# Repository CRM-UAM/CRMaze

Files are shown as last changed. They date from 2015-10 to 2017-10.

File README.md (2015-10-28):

# CRMaze
Open source robot for maze solving + line following

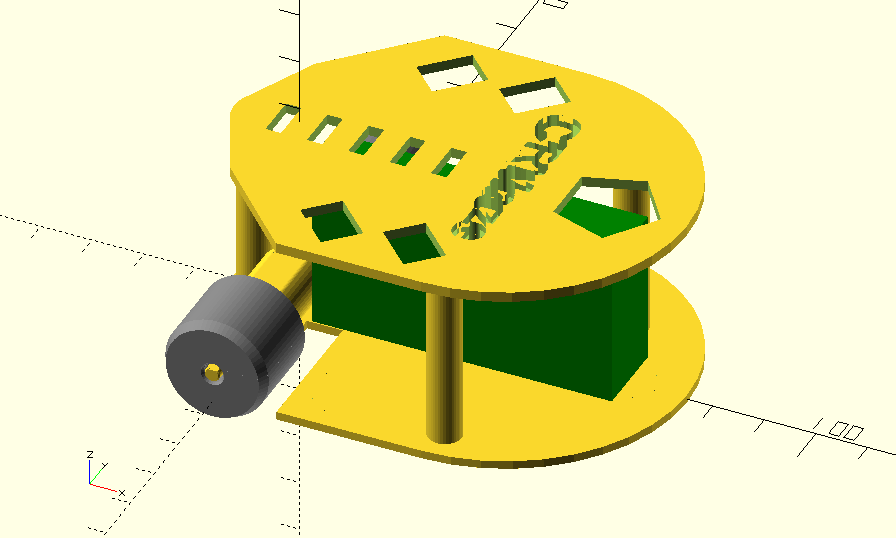
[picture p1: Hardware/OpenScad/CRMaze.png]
  

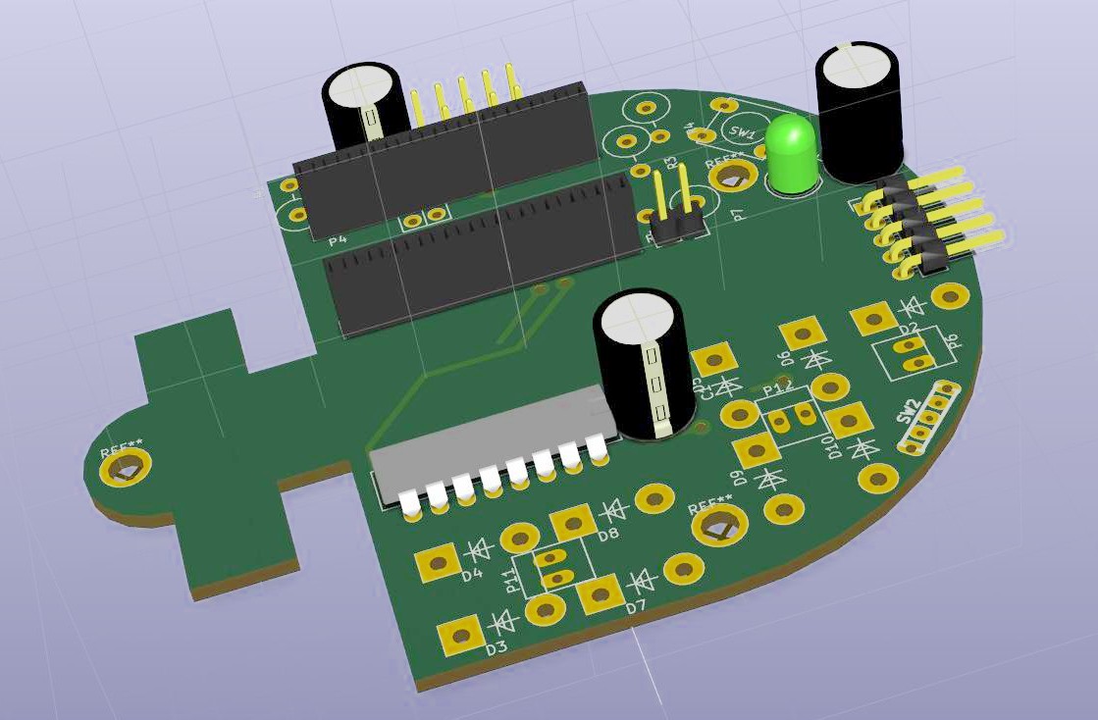
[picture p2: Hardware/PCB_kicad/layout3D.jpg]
  

Authors
--
**Víctor Uceda & Carlos García**  
Club de Robótica-Mecatrónica, Universidad Autónoma de Madrid (CRM-UAM)  
<http://crm-uam.github.io>  

License
--
License: **Attribution - Share Alike - Creative Commons (<http://creativecommons.org/licenses/by-sa/4.0/>)**  

Disclaimer  
--
This hardware/software is provided "as is", and you use the hardware/software at your own risk. Under no circumstances shall any author be liable for direct, indirect, special, incidental, or consequential damages resulting from the use, misuse, or inability to use this hardware/software, even if the authors have been advised of the possibility of such damages.

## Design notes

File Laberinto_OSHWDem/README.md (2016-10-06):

Paredes modulares para probar el laberinto de la OSHWDem
=

Dentro de poco es la OSHWDem Coruña (<http://oshwdem.org/>), el mayor evento que fomenta la tecnología abierta en España.

Una de las competiciones es el laberinto (<http://rules.oshwdem.org/labirinto_es>). Para poder participar, necesitábamos un laberinto en el que probar los robots con cierta antelación.

Para ello hemos diseñado el siguiente sistema paramétrico con las medidas reales que se utilizarán en la competición. Esperemos que os sea de utilidad, y... ¡nos vemos en la OSHWDem! :-)

¡¡¡OJO!!! Las paredes_laberinto.stl son 1cm más largas de la cuenta! Sentimos las molestias que esto haya podido ocasionar... Nos hemos dado cuenta tarde :-S
--

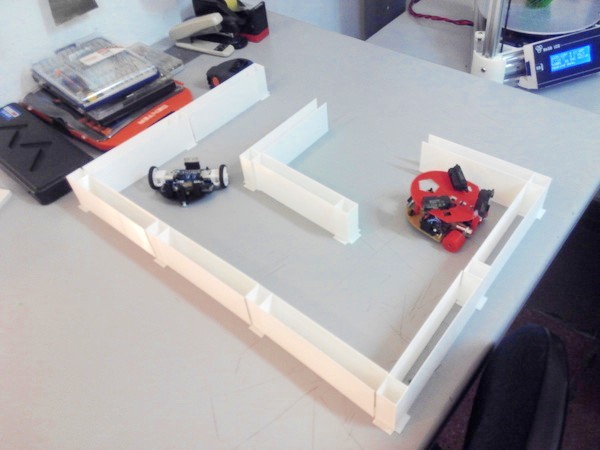
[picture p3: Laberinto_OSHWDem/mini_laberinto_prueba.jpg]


Descarga el diseño
=

- Código fuente OpenSCAD: [paredes_laberinto.scad](paredes_laberinto.scad)
- STL de la pieza suelta: [pieza_suelta.stl](pieza_suelta.stl)
- STL de la base de imprusión: [paredes_laberinto.stl](paredes_laberinto.stl)

Más fotos
=

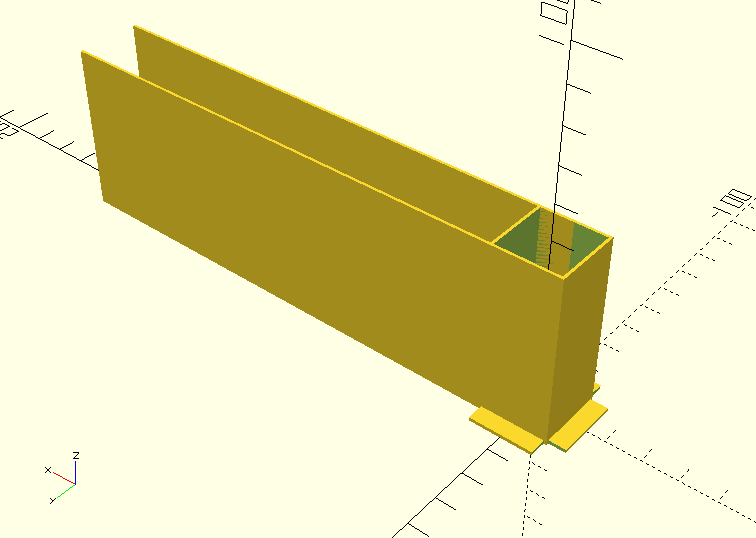
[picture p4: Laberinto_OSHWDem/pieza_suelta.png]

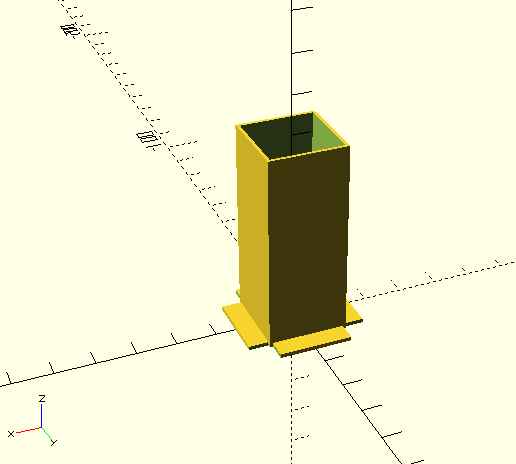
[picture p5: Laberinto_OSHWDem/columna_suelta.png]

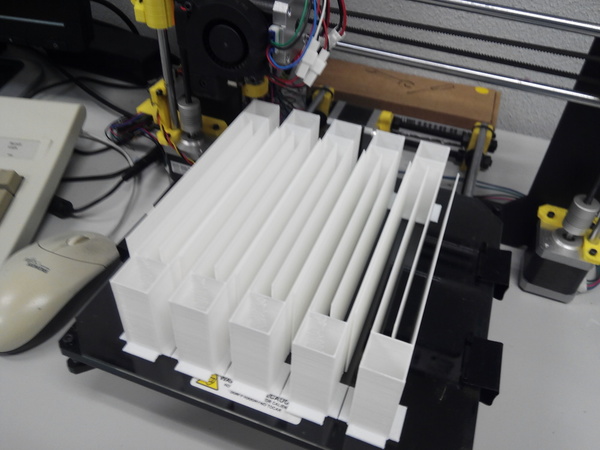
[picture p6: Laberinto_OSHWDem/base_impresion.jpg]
  
*El diseño permite imprimir muchas piezas juntas*  

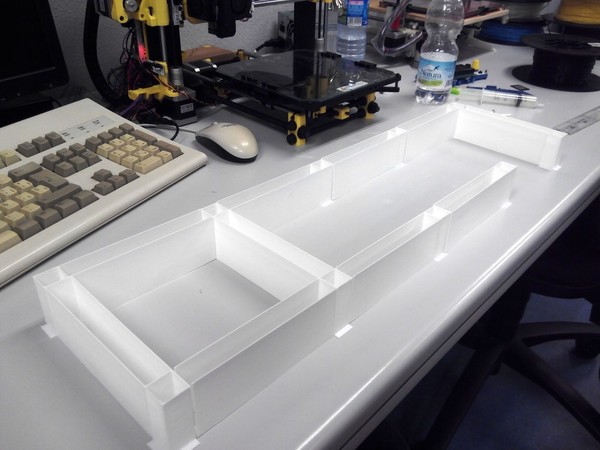
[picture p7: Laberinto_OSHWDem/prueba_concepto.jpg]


Diseñado por Víctor Uceda (@VictorUceda), Eduardo Hilario (@eduhs) y Carlos García (@CarlosGS)

Club de Robótica-Mecatrónica, Universidad Autónoma de Madrid (<http://crm.ii.uam.es>)

Licencia: Public Domain

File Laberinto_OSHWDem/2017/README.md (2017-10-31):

# Pilares para el laberinto de la OSHWDem 2017

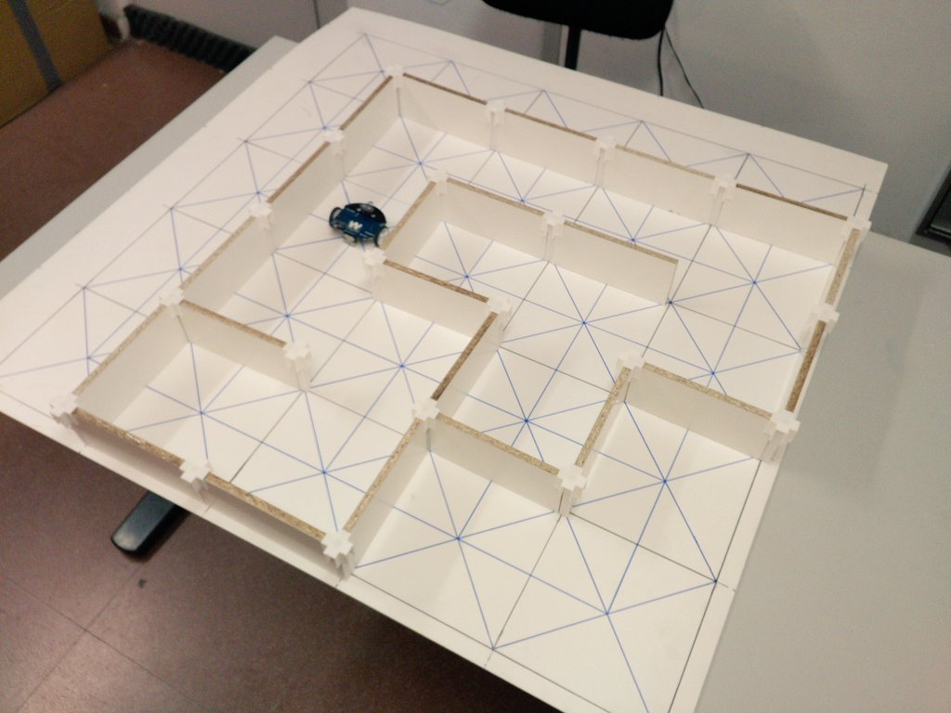
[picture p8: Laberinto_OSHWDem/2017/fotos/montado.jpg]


# Instrucciones

- Cortar tablillas de dimensión 170x80x10mm. Esto lo hacen gratis en la tienda AKI, a partir de tablas de madera conglomerada con laminación blanca.
- Imprimir las columnas de soporte y montarlo como en las fotos.

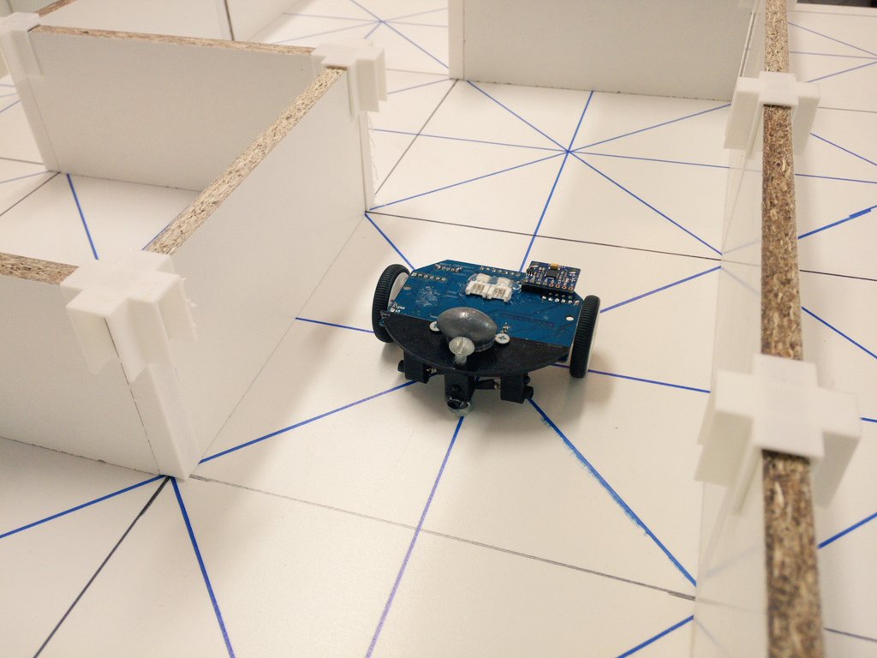
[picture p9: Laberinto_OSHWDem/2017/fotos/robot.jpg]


# Nota: El grosor de las paredes oficiales es 12mm en vez de 10mm. La cuadrícula tiene el mismo tamaño.

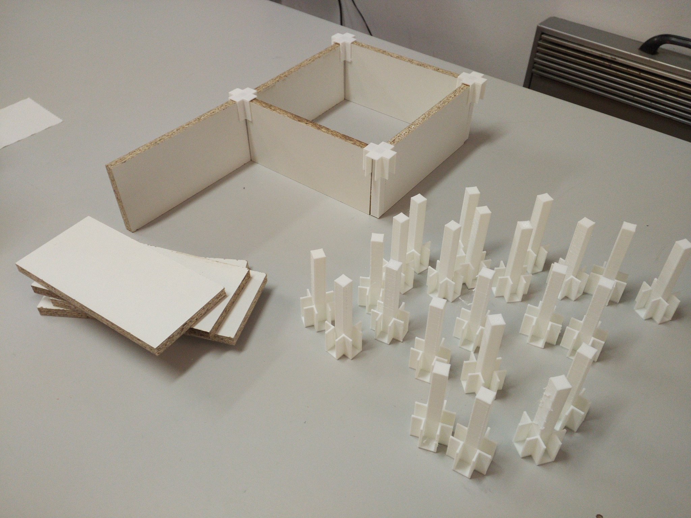
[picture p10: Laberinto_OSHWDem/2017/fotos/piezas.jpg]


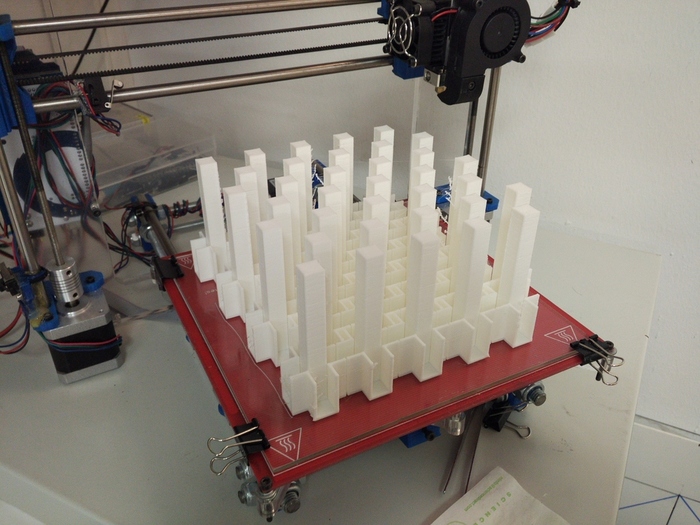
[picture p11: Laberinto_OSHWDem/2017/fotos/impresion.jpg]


# Nota 2: La altura es superior al original para facilitar la fabricación de las tablillas (en el AKI no cortan medidas inferiores).

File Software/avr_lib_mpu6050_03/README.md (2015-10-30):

From <http://davidegironi.blogspot.com.es/2013/02/avr-atmega-mpu6050-gyroscope-and.html>  

==================================================
MPU6050 lib
==================================================
= Copyright (c) Davide Gironi, 2012              =
= http://davidegironi.blogspot.it/               =
==================================================

The MPU-60X0 has an embedded 3-axis MEMS gyroscope, a 3-axis MEMS accelerometer,
and a Digital Motion Processor (DMP) hardware accelerator engine with an
auxiliary I2C port that interfaces to 3rd party digital sensors such
as magnetometers.

Two attitude extimation mode are implemented:
 * internal DMP processor
 * mahony filter

Gyro calibration is suggested to get more accurate parameters. To calibrate the
device read the raw values using the get non calibrated mode then calculate
the offset.

Setup parameters are stored in file mpu6050.h

Devel Notes
-----------
This library was developed on Eclipse, built with avr-gcc on Atmega168 @ 16MHz.
If you include <math.h> add libm library to linker.

License
-------
Please refer to LICENSE file for licensing information.

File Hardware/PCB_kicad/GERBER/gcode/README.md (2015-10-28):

The Gcode files were generated with FlatCAM and post processed:

* all of them were mirrored vertically from bCNC
* the drill file was optimized with bCNC to reduce milling time
* manually removed the "interior" pass of FlatCAM's output, and pocketed the outer edge with bCNC (with the "cut" tool and 0.45mm depth increments)

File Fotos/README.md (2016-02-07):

Participó en la OSHWDem 2015. [Entrada en el blog](http://crm-uam.github.io/blog/2015/11/07/OSHWDem.html)

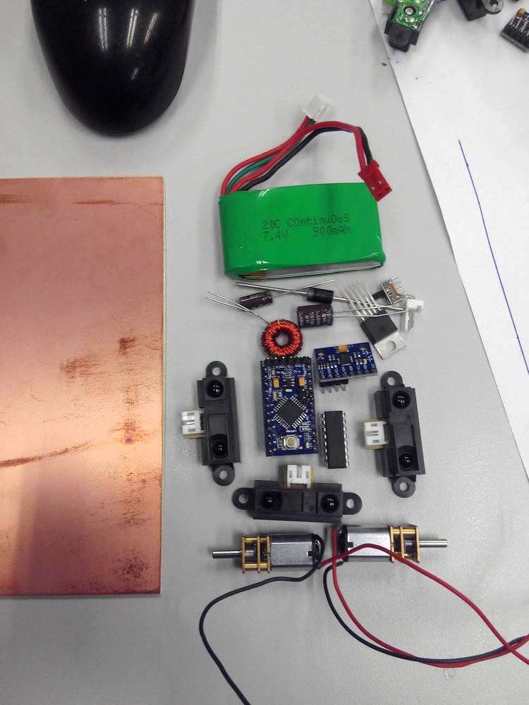
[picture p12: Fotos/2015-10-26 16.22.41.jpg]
foto


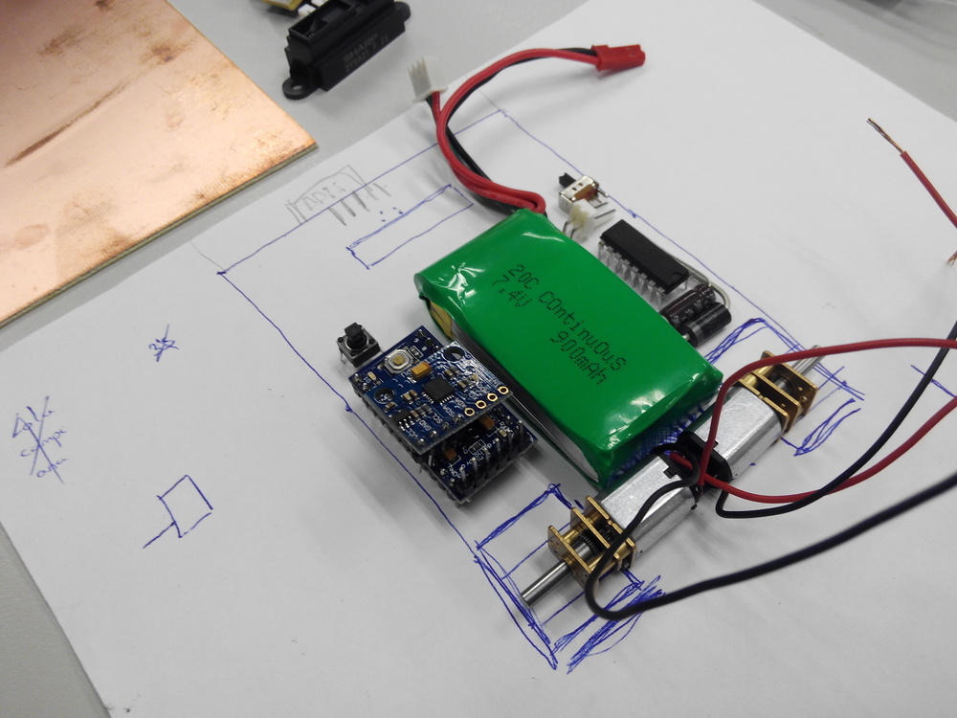
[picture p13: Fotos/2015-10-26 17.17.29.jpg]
foto


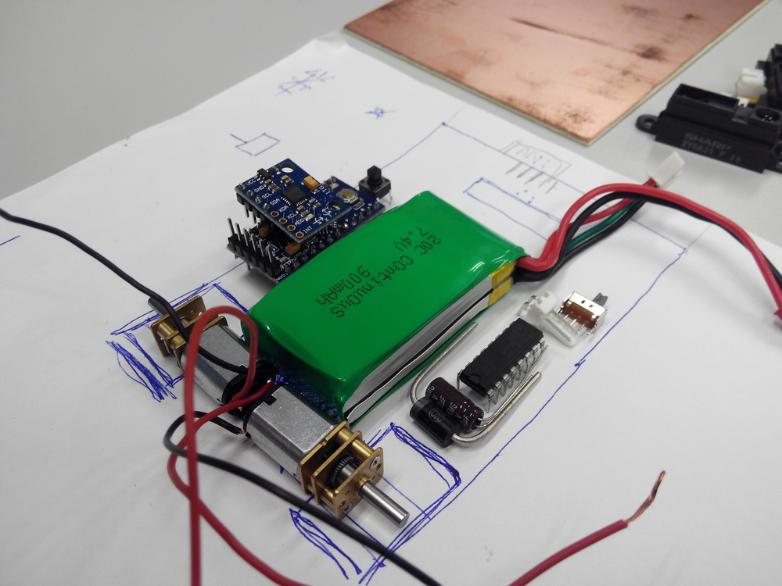
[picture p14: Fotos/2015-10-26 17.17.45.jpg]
foto


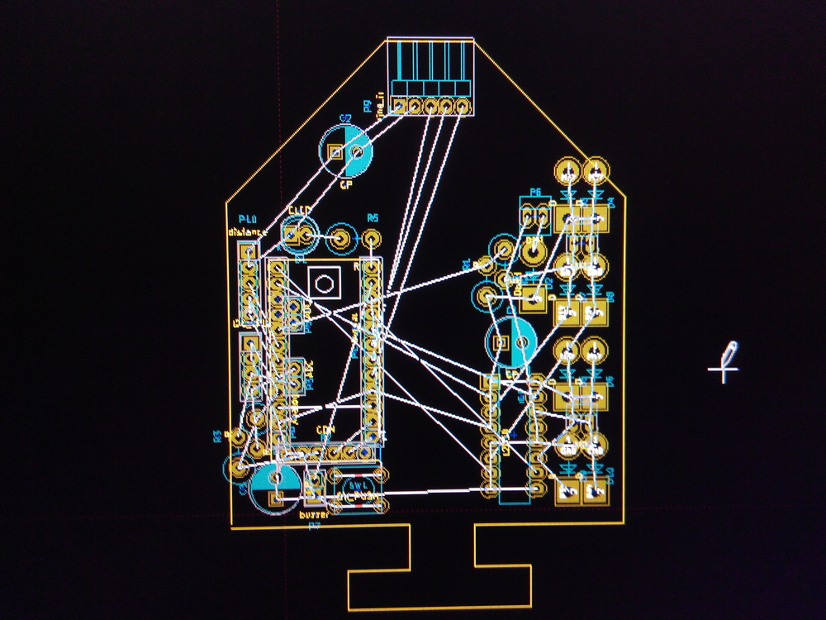
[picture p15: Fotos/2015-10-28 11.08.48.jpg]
foto


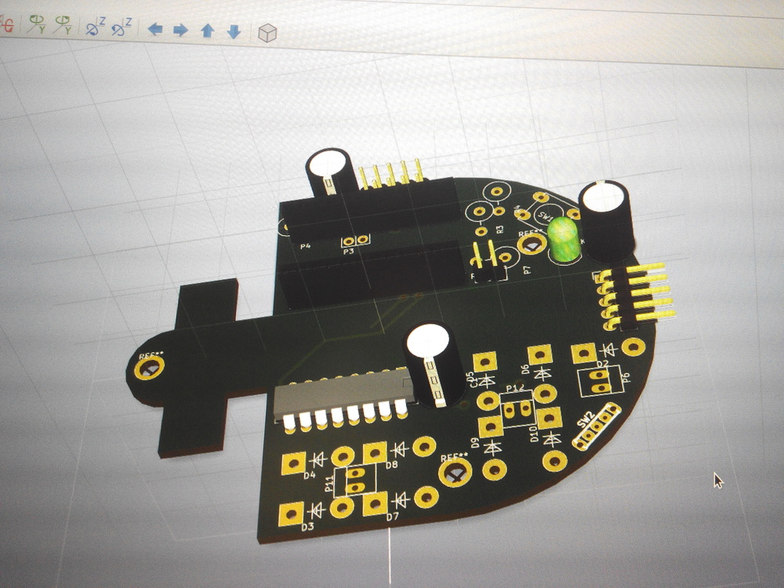
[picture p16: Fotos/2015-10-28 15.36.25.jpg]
foto


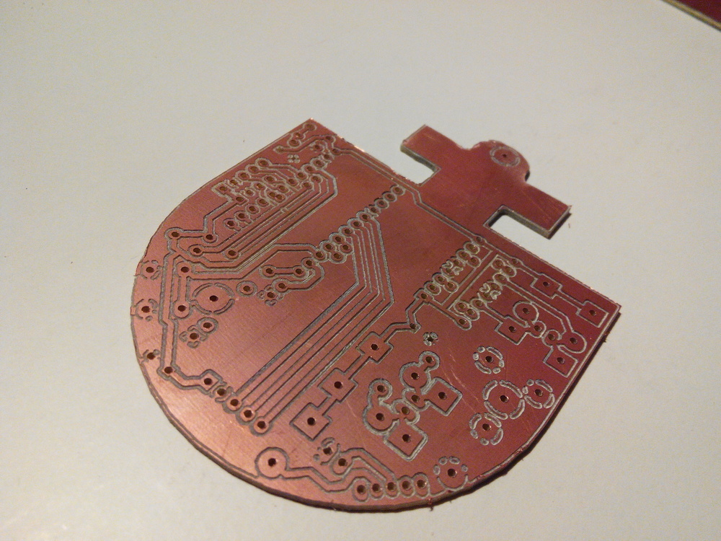
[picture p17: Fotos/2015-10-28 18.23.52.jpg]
foto


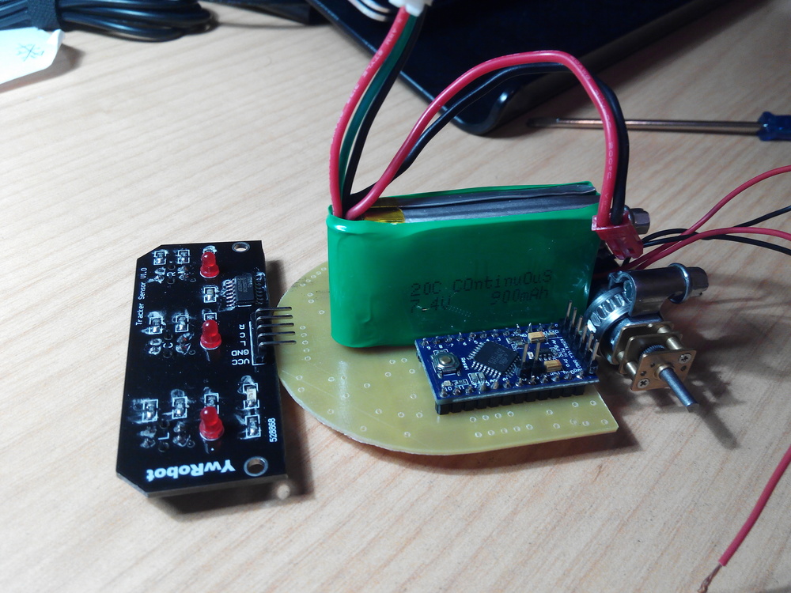
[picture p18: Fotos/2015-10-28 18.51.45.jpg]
foto


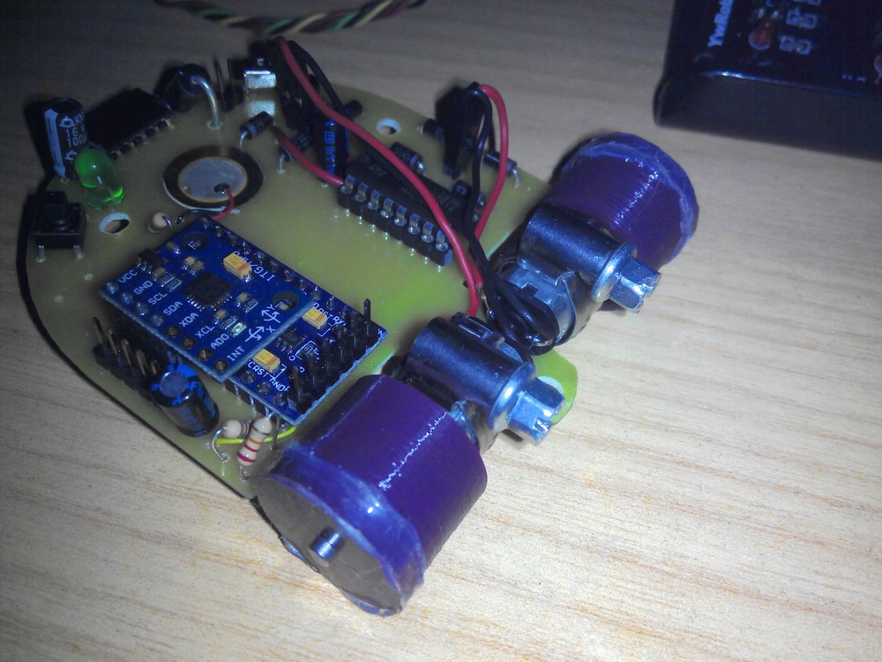
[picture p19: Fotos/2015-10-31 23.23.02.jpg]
foto


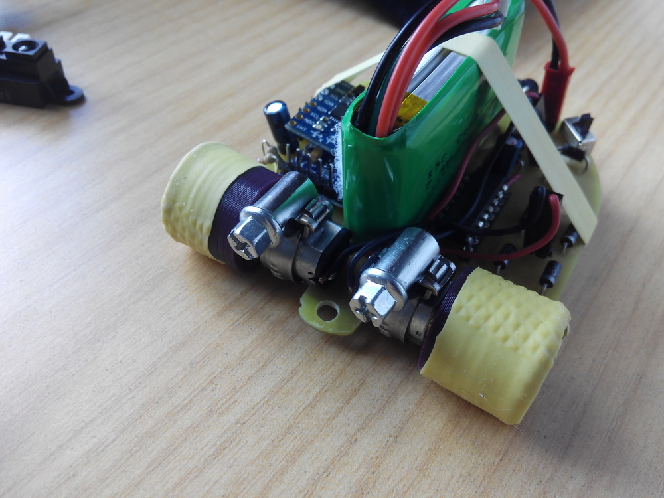
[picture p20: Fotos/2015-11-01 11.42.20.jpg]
foto


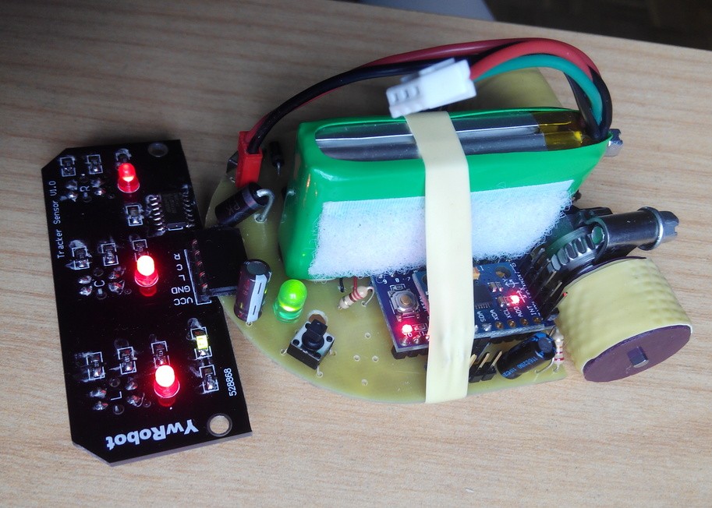
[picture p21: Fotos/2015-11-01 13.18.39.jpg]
foto


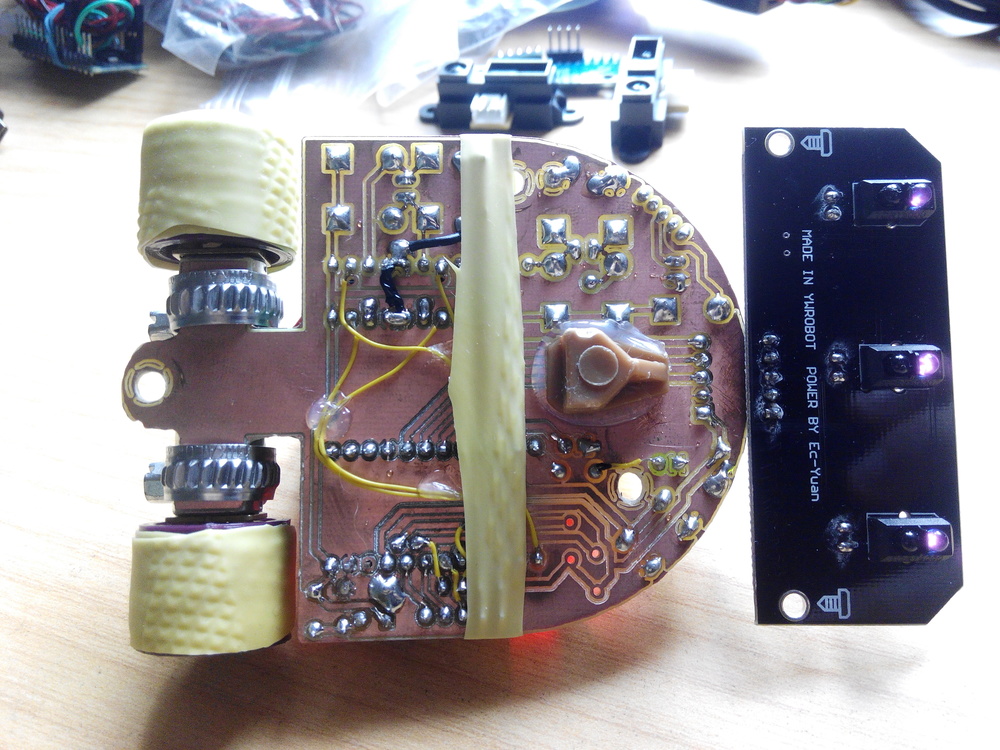
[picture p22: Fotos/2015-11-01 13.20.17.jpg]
foto


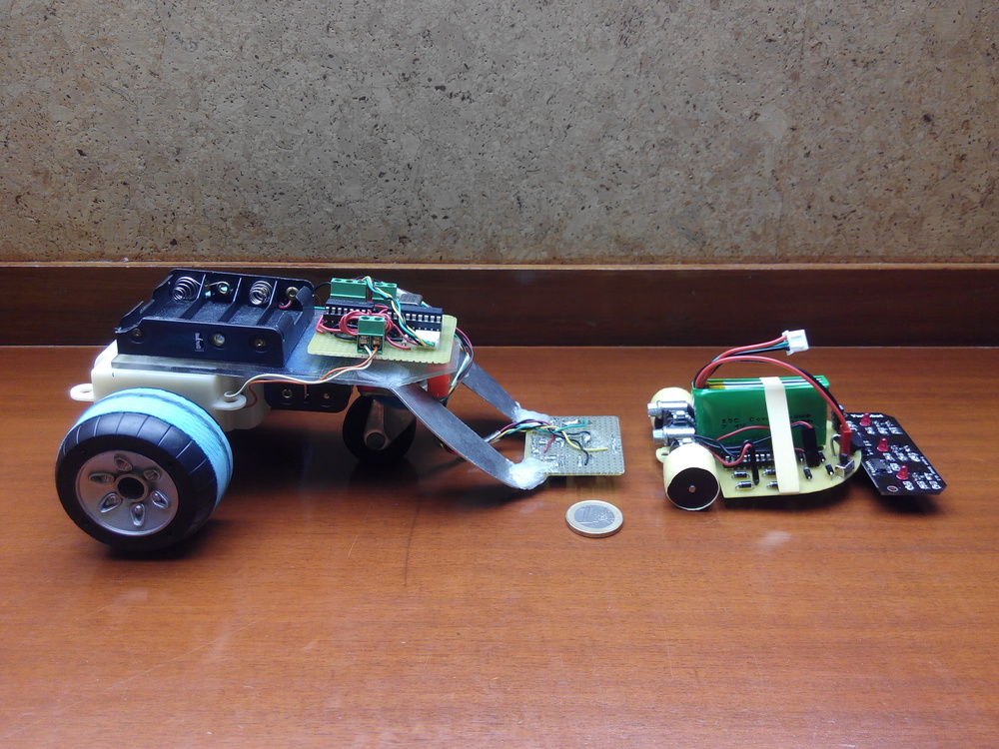
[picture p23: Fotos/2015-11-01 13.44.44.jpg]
foto


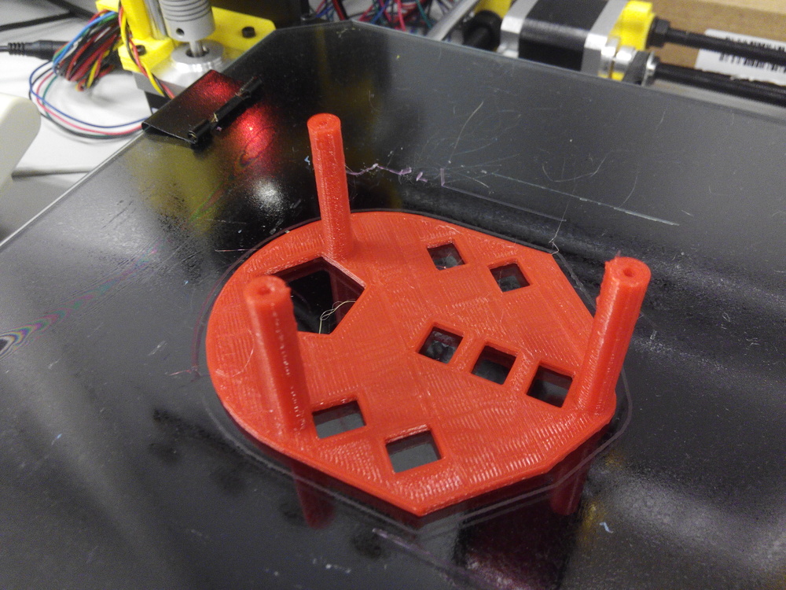
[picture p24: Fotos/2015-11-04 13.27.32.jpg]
foto


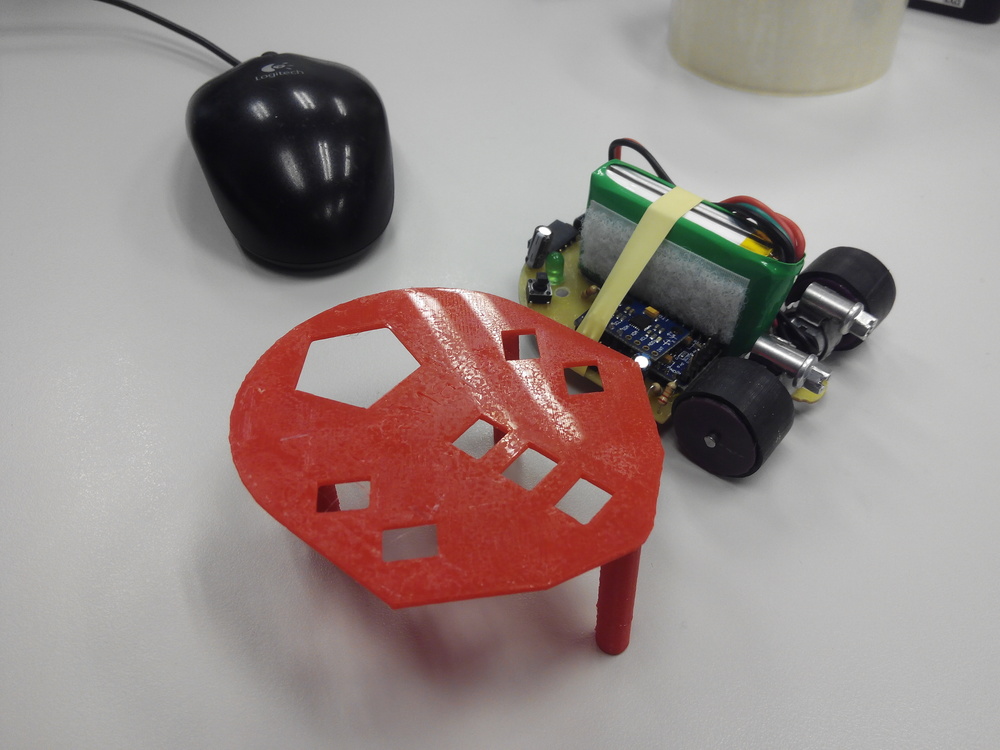
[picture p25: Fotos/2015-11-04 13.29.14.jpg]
foto


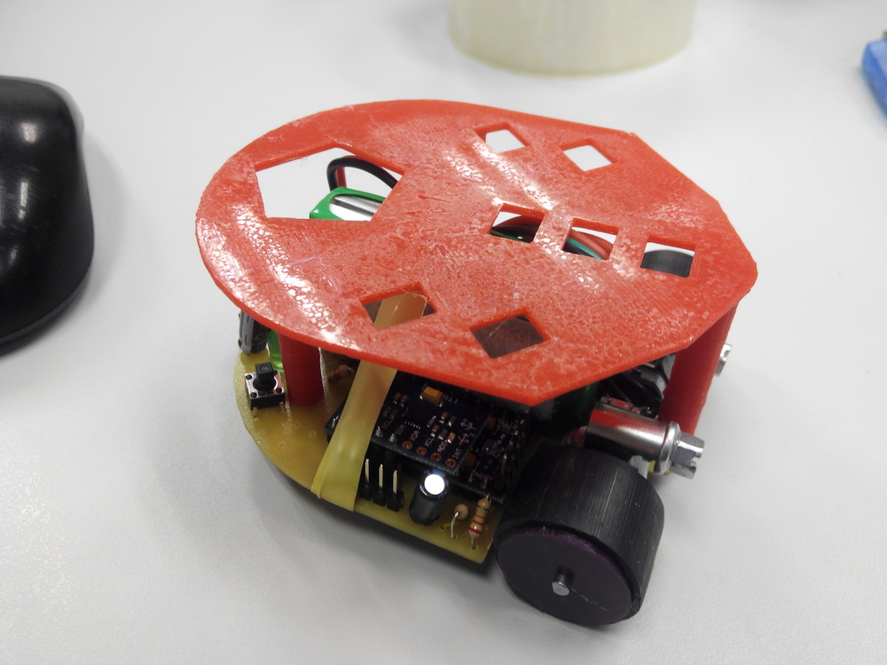
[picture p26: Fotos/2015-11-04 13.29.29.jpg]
foto


foto

foto

foto

foto

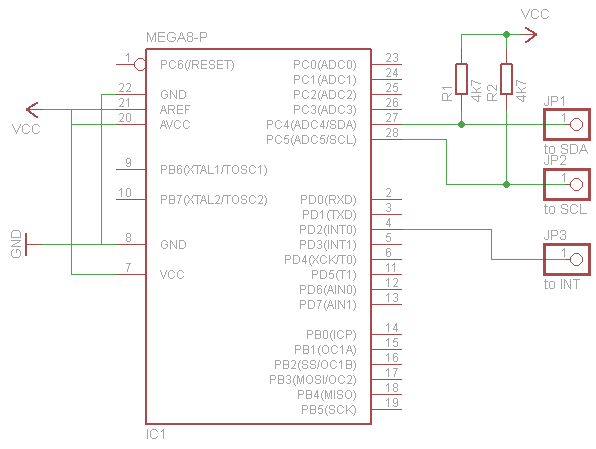
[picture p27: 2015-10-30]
Software/avr_lib_mpu6050_03/schematics/atmega8_mpu6050_sample.png

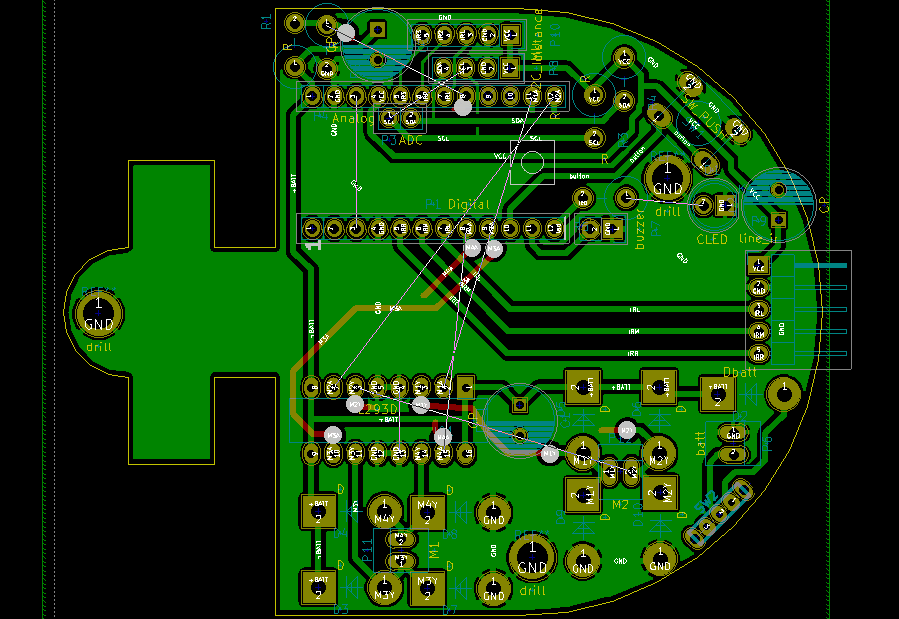
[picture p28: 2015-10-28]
Hardware/PCB_kicad/layout.png

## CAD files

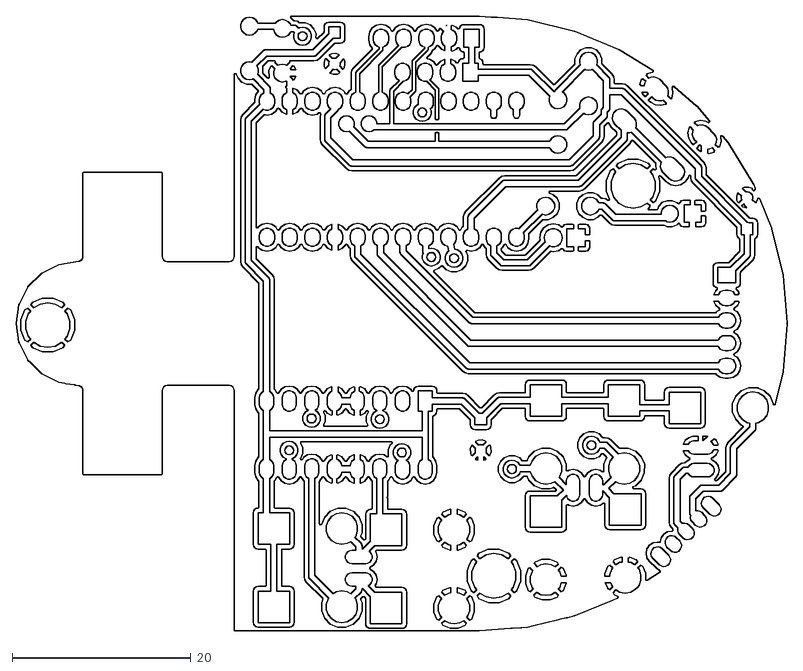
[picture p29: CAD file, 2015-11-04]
Hardware/OpenScad/laberinto-B_Cu.dxf
86.4 x 68.9

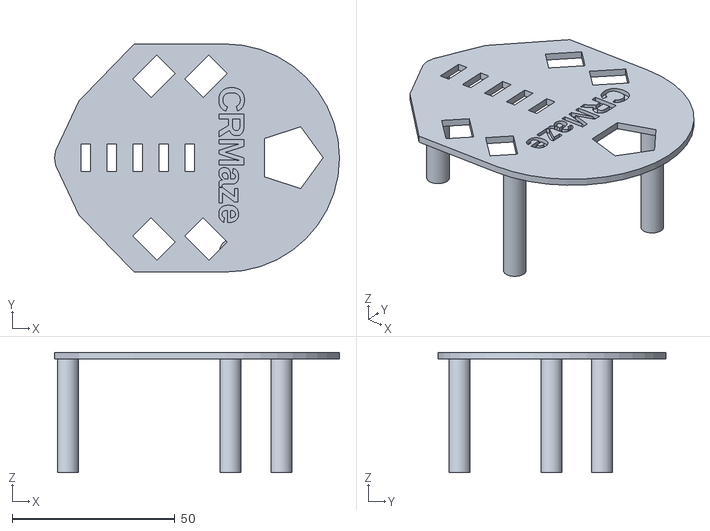
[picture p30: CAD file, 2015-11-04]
Hardware/OpenScad/STLs/sensor_support2.stl
87.6 x 70.1 x 37.0

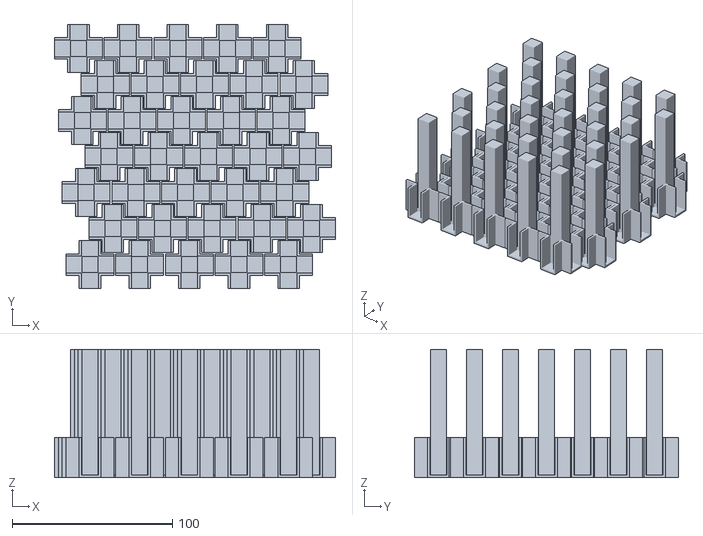
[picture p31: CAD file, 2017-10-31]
Laberinto_OSHWDem/2017/pilaresLaberinto2017.stl
175.5 x 165.0 x 80.0

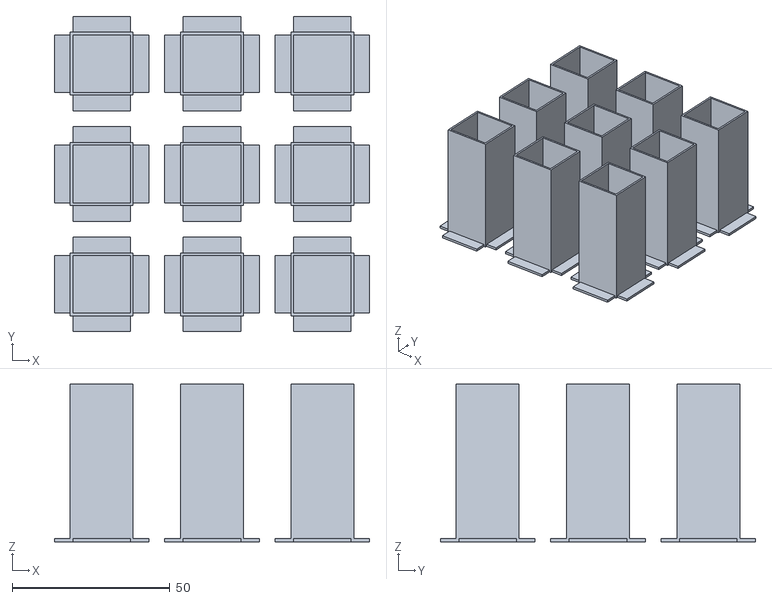
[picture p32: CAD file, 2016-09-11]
Laberinto_OSHWDem/columnas_laberinto.stl
100.0 x 100.0 x 50.0

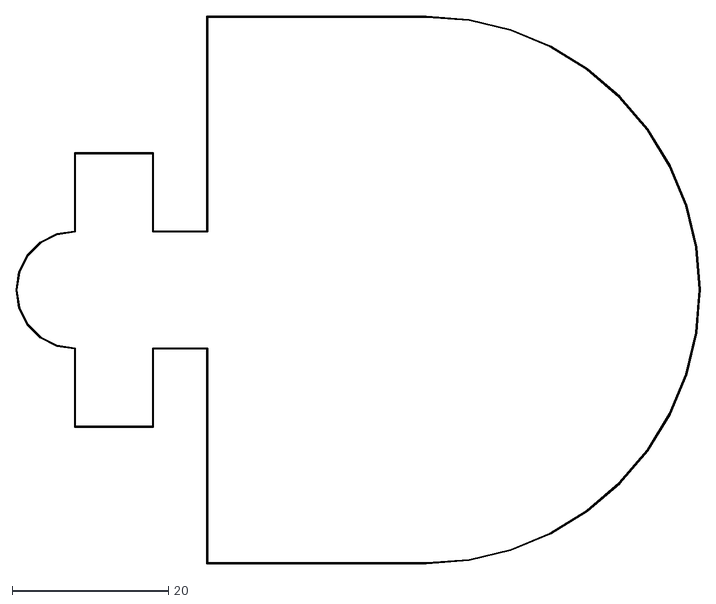
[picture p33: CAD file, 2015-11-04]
Hardware/OpenScad/laberinto-Edge_Cuts.dxf
87.6 x 70.1

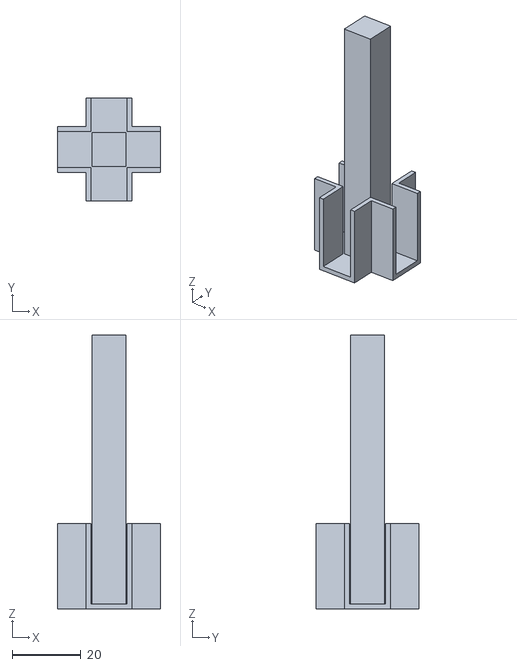
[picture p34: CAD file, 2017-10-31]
Laberinto_OSHWDem/2017/pilarLaberinto2017.stl
30.0 x 30.0 x 80.0

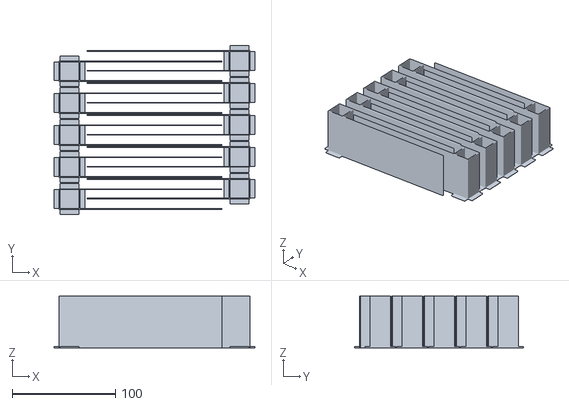
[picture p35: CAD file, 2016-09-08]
Laberinto_OSHWDem/paredes_laberinto.stl
195.0 x 164.0 x 50.0

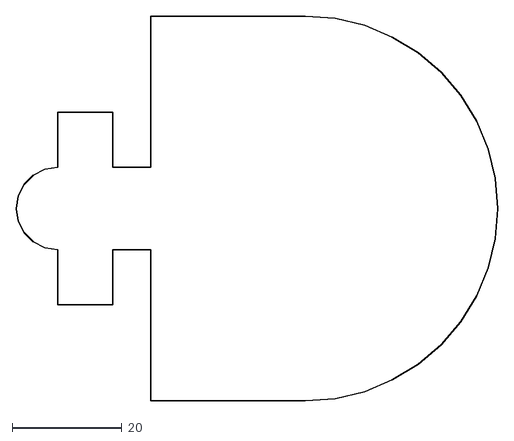
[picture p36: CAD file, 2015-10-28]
Hardware/OpenScad/CRMaze.dxf
87.5 x 70.0

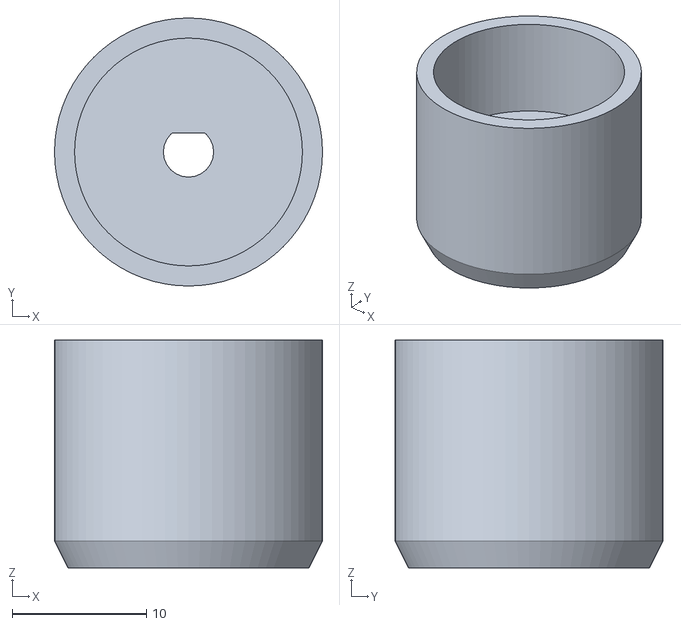
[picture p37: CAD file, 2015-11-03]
Hardware/OpenScad/STLs/wheel.stl
20.0 x 20.0 x 17.0

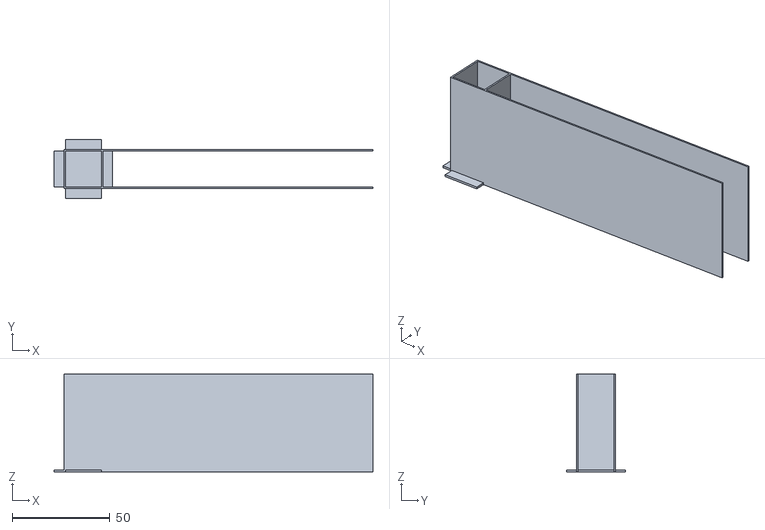
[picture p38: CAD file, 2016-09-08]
Laberinto_OSHWDem/pieza_suelta.stl
163.0 x 30.0 x 50.0

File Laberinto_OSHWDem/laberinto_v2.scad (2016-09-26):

/**
* Código para construir laberinto modular con celdas 15*15cm y paredes de grosor 2c
*/


/**
* Columna de altura h con ranuras desde la parte superior hasta una altura h_ranuras (<h)
*/
module columna(g=1.2, h=70, h_ranuras=28){
    difference(){
        translate([0,0,h/2 ])cube([20,20,h],center=true);
        translate([0,0,h/2+g])cube([20-2*g,20-2*g,h],center=true); 
        
        for(i=[0:4]){
            rotate([0,0,90*i])union(){
            translate([10,3.5,h/2 + h_ranuras/2])cube([4+0.4,g*1.2,h-h_ranuras],center=true);
            translate([10,-3.5,h/2 + h_ranuras/2])cube([4+0.4,g*1.2,h-h_ranuras],center=true);
            }
        }
    }
}

/**
* Pared de altura h con inserciones desde la parte superior hasta una altura h_ranuras (<h)
*/
module pared(g=1.2, h=70, h_ranuras=30){
    translate([65,-5,h/2])cube([128,g,h],center=true);
    
    translate([1+0.6,-1.5,h/2])cube([g,7,h],center=true);
    translate([0,1.5,h/2 + h_ranuras/2])cube([4+0.4,g,h-h_ranuras],center=true);
    translate([-2-0.3,1.5,h_ranuras])cylinder(r=g*0.9,h=h-h_ranuras, $fn=20);

    translate([-1-0.6+130,-1.5,h/2])cube([g,7,h],center=true);
    translate([130,1.5,h/2+h_ranuras/2])cube([4+0.6,g,h-h_ranuras],center=true);
    translate([130+2+0.3,1.5,h_ranuras])cylinder(r=g*0.9,h=h-h_ranuras, $fn=20);
}

*union(){ //bloque de paredes y columnas coladas en la disposición final
%columna();
translate([0,150,0])columna();
translate([150,0,0])columna();

translate([10,-5,0])pared();
translate([140,5,0])rotate([0,0,180])pared();
translate([5,10,0])rotate([0,0,90])pared();
%translate([5,-10-130,0])rotate([0,0,90])pared();
}

module bloque_paredes(dim=10, dim2=4){
    for(i=[0:dim-1]){
        translate([0,i*13,0])pared();
        translate([120,i*13,0])rotate([0,0,180])pared();
    }
    for(i=[0:dim2-1]){
        translate([139+i*13,25,0])rotate([0,0,90])pared();
        translate([139+i*13,140,0])rotate([0,0,-90])pared();
    }
}

module bloque_columnas(dim=10){
    for(i=[0:dim-1]){
        translate([0,i*23,0])union(){
            for(j=[0:dim-1])
                translate([j*23,0,0])columna();
        }
    }
}


*bloque_columnas(8); 
bloque_paredes(14, 4);
%translate([-10,-10,-10])cube([198,198,5]); // base de impresión

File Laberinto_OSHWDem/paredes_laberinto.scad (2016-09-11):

// Paredes modulares para probar el laberinto de la OSHWDem ( http://oshwdem.org/ )
// Diseñado por Víctor Uceda (@VictorUceda), Eduardo Hilario (@eduhs) y Carlos García (@CarlosGS)
// Club de Robótica-Mecatrónica, Universidad Autónoma de Madrid ( http://crm.ii.uam.es )
// Licencia: Public Domain

module columna(complex=true){

    if(complex){
    difference(){
        translate([0,0,0.5]) cube([30,30,1],center=true);
        translate([12.5,12.5,0])cube([6.6,6.6,4],center=true);
        translate([12.5,-12.5,0])cube([6.6,6.6,4],center=true);
        translate([-12.5,12.5,0])cube([6.6,6.6,4],center=true);
        translate([-12.5,-12.5,0])cube([6.6,6.6,4],center=true);
    }
}
difference(){
    translate([0,0,25])cube([20,20,50],center=true);
    translate([0,0,35+0.5])cube([18.4,18.4,70],center=true);
}  
} 


module pieza(complex=true){
    columna(complex);
translate([148/2,10-0.4 ,25])cube([148,0.8,50],center=true);
translate([148/2,-(10-0.4) ,25])cube([148,0.8,50],center=true);
}

module bloque_impresion_piezas(numPiezas=8){
    for(i=[0:numPiezas/2]){
        translate([0,i*31,0])pieza();
    }
    for(i=[0:numPiezas/2]){
        translate([165,10+i*31  ,0])rotate([0,0,180])pieza();
    }
}

module bloque_impresion_columnas(dim=3){
    for(j=[0:dim-1]){
        translate([j*35,0,0])union(){
            for(i=[0:dim-1]){
                translate([0,i*35,0])columna();
            }
        }
    }
}
bloque_impresion_piezas();
%translate([-15,-15,-10])cube([198,198,5]); // base de impresión
*bloque_impresion_columnas();

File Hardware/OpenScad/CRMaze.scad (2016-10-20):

// CRMaze robot
// By Víctor Uceda & Carlos García
//   Club de Robótica-Mecatrónica,
//   Universidad Autónoma de Madrid
//   http://crm-uam.github.io
//
// Derived from:
//   Pololu motor STL by Andrew Taylor ( https://grabcad.com/library/pololu-micro-motor-1-250-reduction-1 )
//   Sharp IR sensor STL by Mojtaba ( https://grabcad.com/library/ir-sensor )


// Increase the resolution of default shapes
$fa = 5; // Minimum angle for fragments [degrees]
$fs = 0.5; // Minimum fragment size [mm]


largo=75;
ancho=70;
grosor=1.6;

tolerancia=0.225;

module rueda(ra=10,ancho=17){
    translate([-6,-5,1]) import("libs/motor.stl");

    color("gray") union() {
        translate([0,0,19])
            difference() {
                hull() {
                    cylinder(r=ra,h=ancho-2);
                    translate([0,0,ancho-2.01]) cylinder(r=ra-1,h=2);
                }
                difference() {
                    cylinder(r=3.3/2+tolerancia,h=ancho+1);
                    translate([-10,1.2+tolerancia,0]) cube([20,20,ancho+2]);
                }
                translate([0,0,ancho+1]) sphere(r=5/2);
                translate([0,0,-0.1]) cylinder(r=8.5,h=9);
            }
    }
   
}

module sharp(){
    scale(10)import("libs/sharp.stl");
}
module bateria(){
    color("green") cube([58,15,30],center=true);
}

module MPU6050(){
   color("blue")cube([4,4,0.9]);
}

module L293(){
    color("black")cube([20,7.1,3],center=true);
}

//color("red")translate([65,0,grosor*2+6])cube([17.8,33,2],center=true);
*translate([largo/2.5,0,0])
    difference(){
        cube([largo,ancho,grosor],center=true);
        translate([-largo/2,ancho/3,0])cube([largo/2.3,ancho/2.3,20],center=true);
        translate([-largo/2,-ancho/3,0])cube([largo/2.3,ancho/2.3,20],center=true);
    }


module pcb() {
    union() {
        translate([-5,0,0])
            cylinder(r=15/2,h=grosor,center=true);
        
        cube([10,35,grosor],center=true);

        translate([20,0,0])
            cube([40,15,grosor],center=true);

        hull() {
        translate([12,0,0])
            cube([0.1,ancho,grosor],center=true);
        /*translate([largo/1.5,0,0])
            cube([0.1,ancho,grosor],center=true);
        translate([largo,0,0])
            cube([0.1,15,grosor],center=true);*/
        translate([largo-ancho/2,0,0])
            difference() {
                cylinder(r=ancho/2,h=grosor,center=true,$fn=40);
                translate([-ancho/2,0,0])
                    cube([ancho,ancho,grosor*2],center=true);
            }
        }
    }
}

translate([0,0,6]) {
    rotate([90,0,0]) rueda();
    rotate([-90,0,0]) rueda();
}

//translate([largo/1.3+largo/9,-ancho/2,30+6])rotate([0,90,0])sharp();
//translate([largo/1.3-largo/9,ancho/2,30+6])mirror([0,1,0])rotate([0,90,0])sharp();
//translate([-10,15,30+6+8])rotate([0,0,-90])sharp();
   
translate([35,0,16]) bateria();
//translate([50,-2,7]) MPU6050(); 
//translate([30,-25,7]) L293(); 

//!projection(cut=true)
    pcb();


dTornillo=3;
xSharp=8;
ySharp=10.5;
difference(){
union() {
    translate([-13.5,-36.5,35]) linear_extrude(height=2) {
        //import("laberinto-B_Cu.dxf");
        hull() import("laberinto-Edge_Cuts.dxf");
    }
   translate([-8.5,-0.2,0])difference(){
        cylinder(d=6.5,h=35);
        translate([0,0,-20])cylinder(d=dTornillo,h=30);
    }
    translate([41.5,-28.5,0])difference(){
        cylinder(d=6.5,h=35);
        translate([0,0,-20])cylinder(d=dTornillo,h=30);
    }
    translate([57.2,15.3,0])difference(){
        cylinder(d=6.5,h=35);
        translate([0,0,-20])cylinder(d=dTornillo,h=30);
    }
}
    translate([60,0,0])cylinder(r=10,h=100,$fn=5);
    translate([38,22,35.7])rotate([0,0,-90])linear_extrude(15)scale(0.8)text("CRMaze", font="Liberation Sans:style=Bold");
    for(i=[0:4]){
        translate([8*i-3,0,0])cube([3,8.5,100],center=true);
    }
    
    translate([34,-25,35])rotate([0,0,45])cube([xSharp,ySharp,10],center=true); 
    translate([34,25,0])rotate([0,0,-45])cube([xSharp,ySharp,100],center=true);
    translate([18,-25,0])rotate([0,0,45])cube([xSharp,ySharp,100],center=true);
    translate([18,25,0])rotate([0,0,-45])cube([xSharp,ySharp,100],center=true);
}

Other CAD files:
Hardware/OpenScad/STLs/sensor_support.stl
Laberinto_OSHWDem/2017/pilaresLaberinto2017.scad

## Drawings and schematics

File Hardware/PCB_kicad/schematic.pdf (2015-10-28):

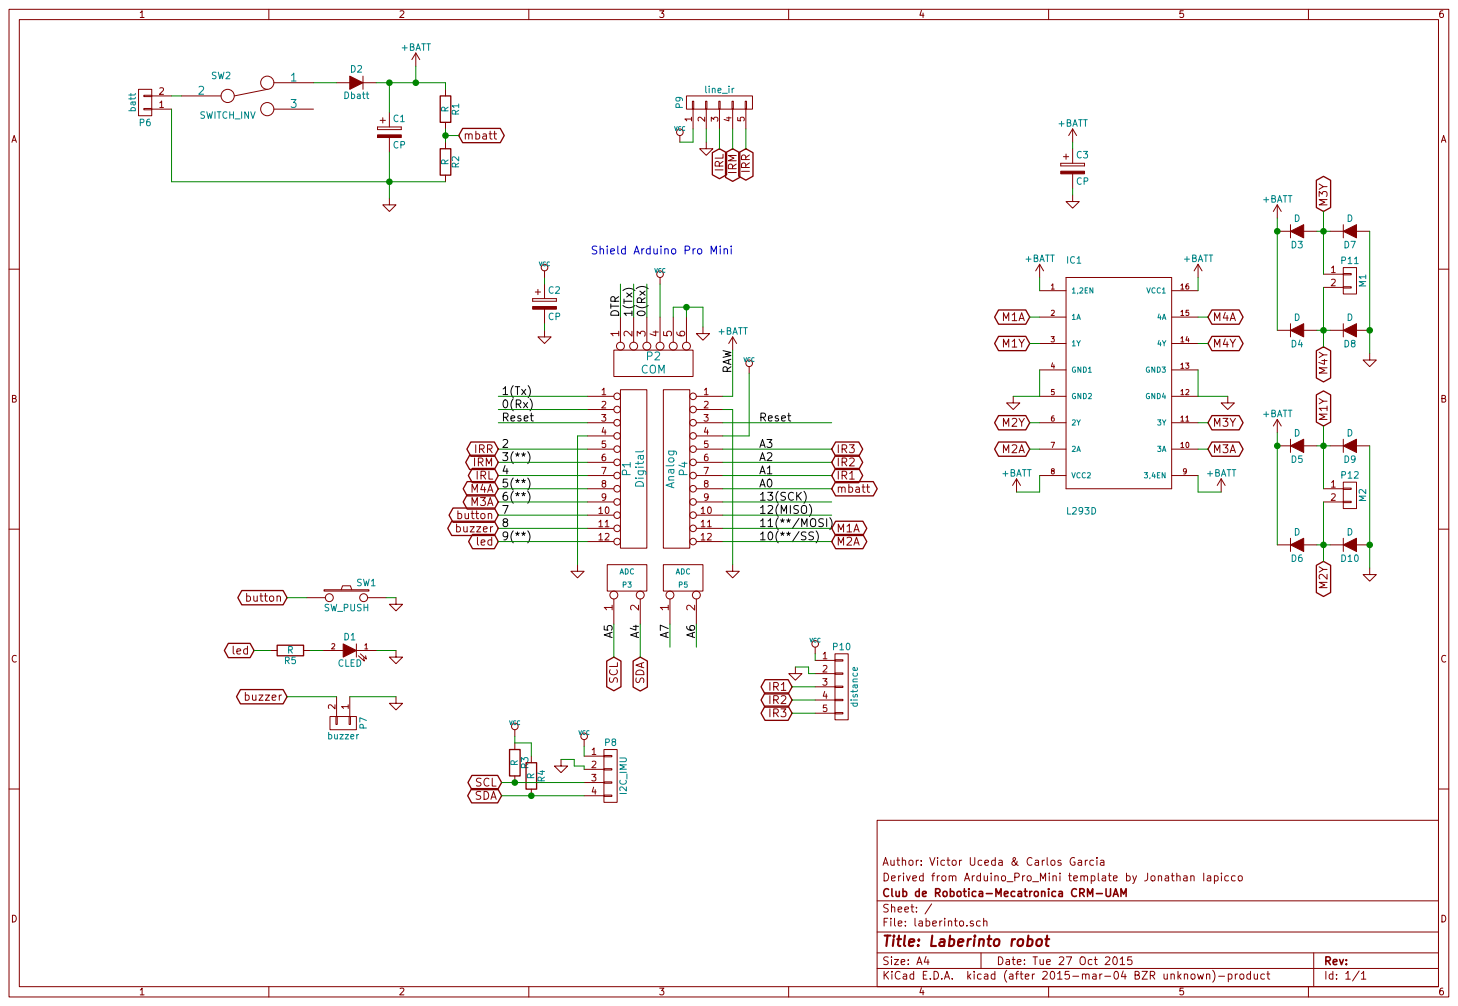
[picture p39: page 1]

VCC DTR 1(Tx) 0(Rx)

Derived from Arduino_Pro_Mini template by Jonathan Iapicco Author: Victor Uceda & Carlos Garcia 123456789

Id: 1/1 Title: Laberinto robot File: laberinto.sch Sheet: / Club de Robotica-Mecatronica CRM-UAM

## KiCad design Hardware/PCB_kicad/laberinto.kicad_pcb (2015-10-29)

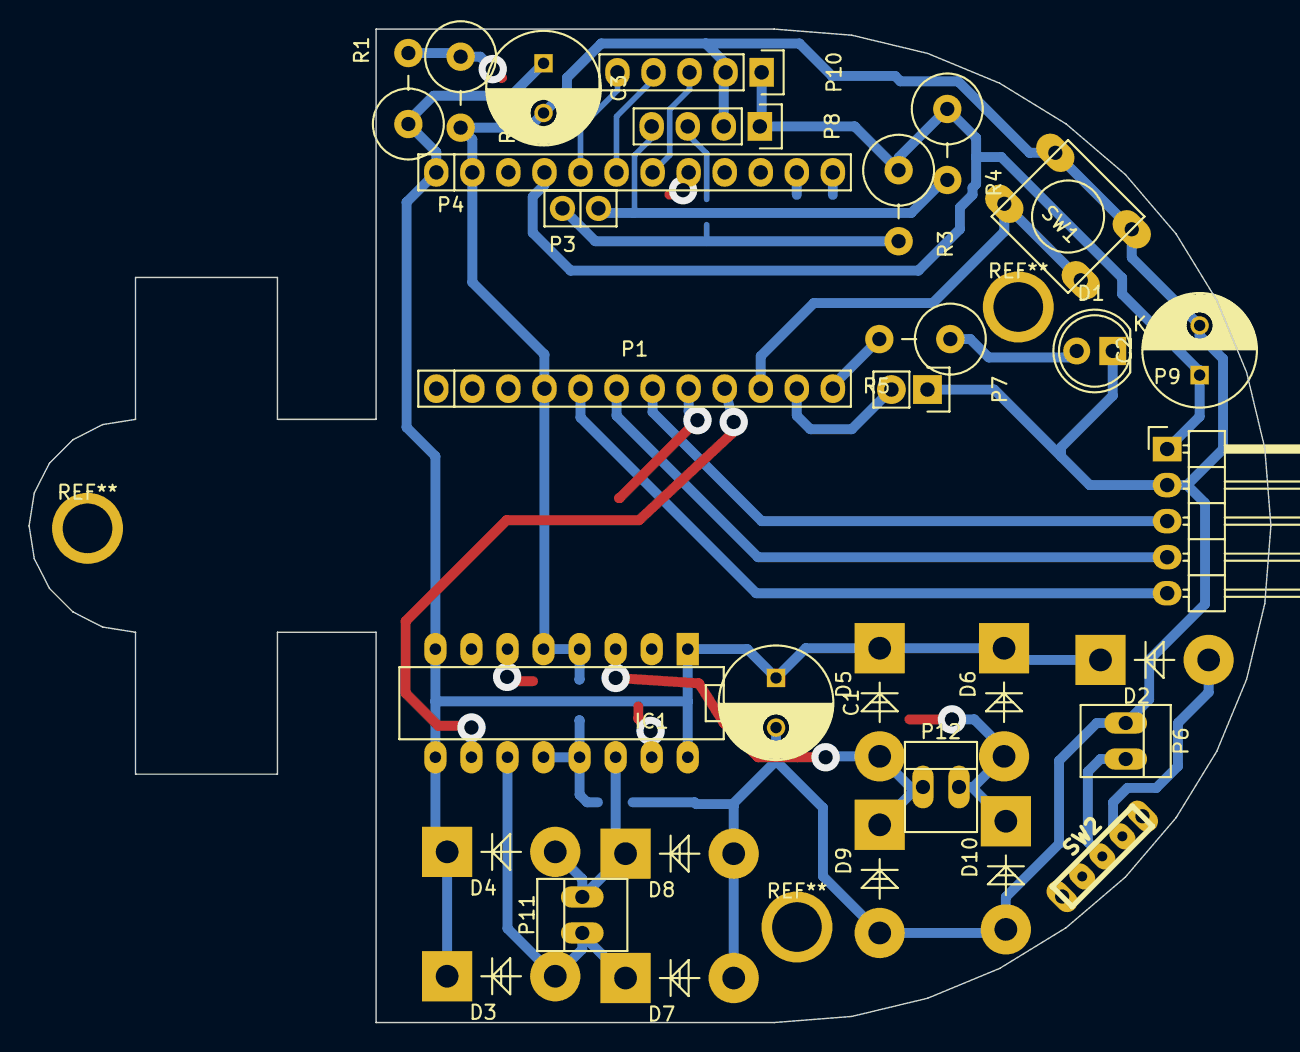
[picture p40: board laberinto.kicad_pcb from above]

Board: 2 copper layers, 87.5 x 70.0 mm, 31 parts (0 on the bottom side), 27 nets.

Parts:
C1, C2, C3: CP; C_Radial_D8_L11.5_P3.5
D1: CLED; LED-5MM
D2: Dbatt; custom_diode
D3, D4, D5, D6, D7, D8, D9, D10: D; custom_diode
IC1: L293D; DIP-16__300_ELL
P1: Digital; Socket_Strip_Arduino_1x12
P3: ADC; Socket_Strip_Arduino_1x02
P4: Analog; Socket_Strip_Arduino_1x12
P6: batt; PINHEAD1-2
P7: buzzer; Pin_Header_Straight_1x02
P8: I2C_IMU; Pin_Header_Straight_1x04
P9: line_ir; Pin_Header_Angled_1x05
P10: distance; Pin_Header_Straight_1x05
P11: M1; PINHEAD1-2
P12: M2; PINHEAD1-2
R1, R2, R3, R4, R5: R; Resistor_Vertical_RM5mm
SW1: SW_PUSH; SW_PUSH_SMALL
SW2: SWITCH_INV; SWITCH_3Pin

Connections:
+BATT: C1.1, C3.1, D2.2, D3.2, D4.2, D5.2, D6.2, IC1.1, IC1.8, IC1.9, IC1.16, P4.1, R1.1
/Reset: P1.3, P4.3
GND: C1.2, C2.2, C3.2, D1.1, D7.1, D8.1, D9.1, D10.1, IC1.4, IC1.5, IC1.12, IC1.13, P1.4, P4.2, P6.1, P7.1, P8.2, P9.2, P10.2, R2.2, SW1.2
IR1: P4.7, P10.3
IR2: P4.6, P10.4
IR3: P4.5, P10.5
IRL: P1.7, P9.3
IRM: P1.6, P9.4
IRR: P1.5, P9.5
M1A: IC1.2, P4.11
M1Y: D5.1, D9.2, IC1.3, P12.1
M2A: IC1.7, P4.12
M2Y: D6.1, D10.2, IC1.6, P12.2
M3A: IC1.10, P1.9
M3Y: D3.1, D7.2, IC1.11, P11.1
M4A: IC1.15, P1.8
M4Y: D4.1, D8.2, IC1.14, P11.2
unnamed: D1.2, R5.1
unnamed: D2.1, SW2.1
unnamed: P6.2, SW2.2
SCL: P3.1, P8.3, R3.2
SDA: P3.2, P8.4, R4.2
VCC: C2.1, P4.4, P8.1, P9.1, P10.1, R3.1, R4.1
button: P1.10, SW1.1
buzzer: P1.11, P7.2
led: P1.12, R5.2
mbatt: P4.8, R1.2, R2.1

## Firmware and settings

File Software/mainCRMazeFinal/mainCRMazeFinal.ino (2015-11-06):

// Code for the CRMaze robot
// By Víctor Uceda & Carlos García
//   Club de Robótica-Mecatrónica,
//   Universidad Autónoma de Madrid
//   http://crm-uam.github.io
// License: CC-BY-SA (http://creativecommons.org/licenses/by-sa/4.0/)
//
// Derived from:
//   GNBot ( https://github.com/carlosgs/GNBot )
//   MPU-6050 Short Example Sketch by Arduino User JohnChi

#include <StackList.h>
//#include <stdarg.h>

//Include custom data types
#include "coord.h"
#include "Order.h"
#include "entry.h"




#define RED_LED_PIN     13
#define GREEN_LED_PIN   9

#define BUZZER_PIN      8

#define M1A_PIN         11
#define M2A_PIN         10
#define M4A_PIN         5
#define M3A_PIN         6

#define BUTTON_PIN      7

#define LINE_R_PIN      2
#define LINE_M_PIN      3
#define LINE_L_PIN      4

#define DIST_3_PIN      A3
#define DIST_2_PIN      A2
#define DIST_1_PIN      A1

#define BATTERY_V_PIN   A0




#include<Wire.h>

const int MPU=0x68;  // I2C address of the MPU-6050

#define MPU6050_PWR_MGMT_1    0x6B
#define MPU6050_GYRO_CONFIG   0x1B

void IMUwriteReg(byte reg, byte val) {
  Wire.beginTransmission(MPU);
  Wire.write(reg);
  Wire.write(val);
  Wire.endTransmission(true);
}

int16_t GyZoffset;
float yaw;
unsigned long prev_ts;

void init_IMU() {
  Wire.begin();

  // Measure gyro sensor offset (robot must remain still)
  GyZoffset = 0;
  for(int i=0; i<10; i++)
    GyZoffset += readGyro_raw();
  GyZoffset /= 10;
  //Serial.println("Gyro offset:");
  //Serial.println(GyZoffset);

  IMUwriteReg(MPU6050_PWR_MGMT_1, bit(7) );  // DEVICE_RESET to 1 (D7=1)
  delay(100);
  IMUwriteReg(MPU6050_PWR_MGMT_1, 0 ); // set SLEEP to zero (D6=0, wakes up the MPU-6050)
  IMUwriteReg(MPU6050_GYRO_CONFIG, bit(3) | bit(4) ); // set sensitivity to +-2000deg/s (D3=1, D4=1)

  yaw = 0;
}

int16_t readGyro_raw() {
  Wire.beginTransmission(MPU);
  Wire.write(0x47);  // starting with register 0x47 (GYRO_ZOUT_H)
  Wire.endTransmission(false);
  Wire.requestFrom(MPU,2,true);  // request a total of 12 registers
  return Wire.read()<<8 | Wire.read();  // 0x47 (GYRO_ZOUT_H) & 0x48 (GYRO_ZOUT_L)
}

// Outputs the robot's rotational speed (yaw) in degrees/second
float readGyro() {
  return (readGyro_raw()-GyZoffset)*2000./32768.; // +-2000 deg/s sensitivity; +-2^15 full scale
}

float updateGyro(float rotationalSpeed) {
  unsigned long ts = micros();
  float dt = ((float)(ts-prev_ts))/1000000.;
  if(dt > 0 && dt < 0.5) { // Ensures the integration only over sensible sampling intervals
    yaw += rotationalSpeed*dt;
  }
  prev_ts = ts;
  return dt;
}



// Music notes
#define DO 262
#define RE 294
#define MI 330
#define FA 349
#define SOL 392
#define LA 440
#define SI 494

void playNote(int frequency, int length) {
    if(frequency <= 0) frequency = DO;
    if(length <= 0) length = 100;
    //tone(BUZZER_PIN,frequency);
    delay(length);
    //noTone(BUZZER_PIN);
    delay(100);
}




float mapf(float x, float in_min, float in_max, float out_min, float out_max) {
  return (x - in_min) * (out_max - out_min) / (in_max - in_min) + out_min;
}



void init_motor_pins() {
  pinMode(M1A_PIN,OUTPUT);
  pinMode(M2A_PIN,OUTPUT);
  pinMode(M3A_PIN,OUTPUT);
  pinMode(M4A_PIN,OUTPUT);
}

// Input: [-255,+255] (positive values move the robot forward)
void Lmotor_PWM(int16_t vel) {
  if(vel > 0) {
    analogWrite(M1A_PIN, 0);
    analogWrite(M2A_PIN, vel);
  } else if(vel < 0) {
    analogWrite(M1A_PIN, -vel);
    analogWrite(M2A_PIN, 0);
  } else {
    analogWrite(M1A_PIN, 255);
    analogWrite(M2A_PIN, 255);
  }
}

// Input: [-255,+255] (positive values move the robot forward)
void Rmotor_PWM(int16_t vel) {
  if(vel > 0) {
    analogWrite(M3A_PIN, 0);
    analogWrite(M4A_PIN, vel);
  } else if(vel < 0) {
    analogWrite(M3A_PIN, -vel);
    analogWrite(M4A_PIN, 0);
  } else {
    analogWrite(M3A_PIN, 255);
    analogWrite(M4A_PIN, 255);
  }
}

// Calibrated motor functions (cm/s)
#define motorDeadZonePWM 20
#define motorK_PWM       50
#define motorK_CMs       28.
int16_t map_vel_pwm(float vel) {
  int16_t res = 0;
  if(vel > 0)
    res = mapf(vel, 0,motorK_CMs, motorDeadZonePWM, motorK_PWM);
  if(vel < 0)
    res = mapf(vel, 0,-motorK_CMs, -motorDeadZonePWM, -motorK_PWM);
  return round(max(min(res,255),-255));
}

void set_motor_speed(float velocity, float offset) {
  Lmotor_PWM(map_vel_pwm(velocity+offset));
  Rmotor_PWM(map_vel_pwm(velocity-offset));
}



// --- BUTTON ---
void init_button_pin() {
  pinMode(BUTTON_PIN,INPUT);
  digitalWrite(BUTTON_PIN, HIGH); // Enable internal pull-up resistor
}

bool button_is_pressed() {
  return !digitalRead(BUTTON_PIN);
}




float getDistanceCM(int pin) {
  float measurement = analogRead(pin);
  float ir_K = 4419.36; // Linearization of the sensor response
  float ir_C = 32.736;
  if(measurement <= ir_C) return 150;
  float res = ir_K/(measurement-ir_C);
  if(res < 0 || res > 150) res = 150;
  return res;
}

float getBatteryVoltage() {
  int val = analogRead(BATTERY_V_PIN);
  return mapf(val,0,1023, 0,21.1765); // Voltage divider with 22k in series with 6k8
}





float kp = 4;
float kd = 0.05;
float ki = 0.5;

int motorPIDcontroller(float yawGoal, boolean term_yawReached, float c_speed, float IRdistGoal_cm, boolean term_IRdistReached, float yawEnd, float distanceGoal, boolean term_distanceReached) {
  float prev_error = 0;
  boolean saturated = false;
  boolean first_iteration = true;
  float error_integral = 0;
  float error_derivative = 0;
  float distance_integral = 0;
  while(1) {
    float rotationalSpeed = readGyro();
    float dt = updateGyro(rotationalSpeed);

    float distR = getDistanceCM(DIST_1_PIN);
    float distL = getDistanceCM(DIST_3_PIN);

    if(button_is_pressed()) {
      set_motor_speed(0, 0);
      while(1);
    }

    float targetYaw = yawGoal;
    if(term_distanceReached) targetYaw = mapf(distance_integral,0,distanceGoal,yawGoal,yawEnd);
    float error = 0;//2*(distR-15);//(yaw-targetYaw);
    if(term_yawReached)
      error = (yaw-targetYaw);
    else {
      if(distR < 20) error = (distR-12);
      if(distL < 20 && distL < distR) error = -(distL-12);
    }
    while(error > 180) error -= 360;
    while(error <= -180) error += 360;

    if(!first_iteration) {
      if(!saturated) error_integral += prev_error*dt;
      error_derivative = (error-prev_error)/dt;
      distance_integral += c_speed*dt;
      if(term_distanceReached) {
          if(c_speed > 0) {
              if(distance_integral > distanceGoal-c_speed*dt) return 3;
          } else {
              if(distance_integral < distanceGoal+c_speed*dt) return 3;
          }
      }
    } else first_iteration = false;

    if(term_yawReached && abs(error)+abs(error_integral)+abs(error_derivative) < 10) return 1;
    if(term_IRdistReached) {
        float dist = getDistanceCM(DIST_2_PIN);
        if(c_speed > 0) {
            if(dist < IRdistGoal_cm) return 2;
        } else {
            if(dist > IRdistGoal_cm) return 2;
        }
    }

    float v = kp*error + ki*error_integral + kd*error_derivative;

    if(abs(v)>400) {
      saturated = true;
    } else {
      if(saturated) error_integral = 0;
      saturated = false;
    }

    set_motor_speed(c_speed, v);

    prev_error = error;
  }
}

void turn(float yawGoal) {
    //motorPIDcontroller(yaw+yawGoal, true, 0, 0, false, 0, 0, false);
    float rotVel = 30;
    yawGoal += yaw;
    float error = yaw-yawGoal;
    while(error > 180) error -= 360;
    while(error <= -180) error += 360;

    if(error < 0) rotVel *= -1;

    set_motor_speed(10, rotVel);
    while(abs(error) > 10) {
      float rotationalSpeed = readGyro();
      float dt = updateGyro(rotationalSpeed);
      if((yaw-yawGoal)*error < 0) break;
      error = yaw-yawGoal;
    }
    set_motor_speed(0, 0);
    delay(1000);
}







#define NORTH 1
#define SOUTH 2
#define EAST 4
#define WEST 8
  //Define some global constants
  #define X 13
  #define Y 13

float getDistanceCM(int);
  entry maze[Y][X]; //maze matrix ¡¡Cuidado usa la Y y la X al reves ya que maze[0] es la FILA superior!!
  uint8_t headings[] = {1,2,4,8}; //N,S,E,W

//Variables para simulacion de un laberinto y comprobar la correccion
  uint8_t posXrobot=0;
  uint8_t posYrobot=0;
  uint8_t headingRobot=2;
  int totalMove=0;




/*void pf(char *fmt, ... ){
        char buf[128]; // resulting string limited to 128 chars
        va_list args;
        va_start (args, fmt );
        vsnprintf(buf, 128, fmt, args);
        va_end (args);
        //Serial.print(buf);
}*/

void instantiate(){
  for(uint8_t j = 0; j<Y; j++){
    for(uint8_t i = 0; i<X; i++){
      maze[j][i].distance = calcCenter(i, j, X);
      maze[j][i].walls = 15;
      //If this is the left column (0,x)
      if(i==0){
        maze[j][i].walls = 7;
      }
      //if this is the top row
      if(j==0){
        maze[j][i].walls = 14;
      }
      //if this is the bottom row
      if(j==(Y-1)){
        maze[j][i].walls = 13;
      }
      //If this is the righ column
      if(i==(X-1)){
        maze[j][i].walls = 11;
      }
      maze[0][0].walls = 6;
      maze[Y-1][0].walls = 5;
      maze[0][X-1].walls = 10;
      maze[X-1][Y-1].walls = 9;
    }
  }
}
//Get the most optimistic distance between two coordinates in a grid
uint8_t calcDist(uint8_t posx, uint8_t posy, uint8_t desireX, uint8_t desireY){
  uint8_t dist = abs(desireY-posy)+abs(desireX-posx);
  return dist;
}

//Get the most optimistic distance between a given coordinate and a
//3x3 square in the center of a maze of dimension dim (dim must be even)
uint8_t calcCenter(uint8_t posx, uint8_t posy, uint8_t dim){
  uint8_t center = dim/2;
  uint8_t dist = 0;

  if(posy < center){
    if(posx < center){
      //You're in the top left of the maze
      dist=calcDist(posx, posy, (center-1), (center-1));
    }else if(posx == center){
      dist=calcDist(posx, posy, center, (center-1));
    }else{
      //You're in the bottom left of the maze
      dist=calcDist(posx,posy, (center+1),(center-1));
    }
  }else if(posy == center){
    if(posx < center){
      //You're in the top center of the maze
      dist=calcDist(posx, posy, center-1, center);
    }else if(posx == center){
      dist=0;
    }else{
      //You're in the bottom center of the maze
      dist=calcDist(posx,posy, center+1,center);
    }
  }else{
    if(posx < center){
      //You're in the bottom left of the maze
      dist=calcDist(posx,posy,(center - 1),(center + 1));
    }else if(posx == center){
      dist=calcDist(posx, posy, center, (center + 1));
    }else{
      //You're in the bottom right of the maze
      dist=calcDist(posx,posy,(center + 1),(center + 1));
    }
  }
return dist;
}

/*
INPUT: a coordinate representing a current position, and a heading
OUTPUT: the coordinates of the next desired position based on the heading and current position
*/
Coord bearingCoord(Coord currCoord, uint8_t heading){
  Coord nextCoord (0,0);
  switch (heading){
    case 1:
      //code
      nextCoord.setX(currCoord.getX());
      nextCoord.setY(currCoord.getY()-1);
      break;
    case 2:
      nextCoord.setX(currCoord.getX());
      nextCoord.setY(currCoord.getY()+1);
      break;
    case 4:
      nextCoord.setX(currCoord.getX()+1);
      nextCoord.setY(currCoord.getY());
      break;
    case 8:
      nextCoord.setX(currCoord.getX()-1);
      nextCoord.setY(currCoord.getY());
      break;
  }
  return nextCoord;
}

/*
INPUT: A Coord representing the current coordiante and the robots current heading
OUTPUT: An optimal direction away from the current coordinate.
*/
uint8_t orient(Coord currCoord, uint8_t heading){
  //printMaze();
  //pf("DEBUG orient (%d,%d-%d)\n",currCoord.x,currCoord.y,heading);
  Coord leastNext (0,0);
  //This is the absolute largest value possible (dimension of maze squared)
  uint8_t leastNextVal = 255;
  uint8_t leastDir = heading;


  if((maze[currCoord.getY()][currCoord.getX()].walls & heading) != 0){
    Coord leastnextTemp = bearingCoord(currCoord, heading);
    if(checkBounds(leastnextTemp)){
      leastNext = leastnextTemp;
      leastNextVal = maze[leastNext.getY()][leastNext.getX()].distance;
    }
  }
  for(uint8_t i=0; i<4; i++){
    uint8_t dir = headings[i];
    //if this dir is accessible
    if((maze[currCoord.getY()][currCoord.getX()].walls & dir) != 0){
      //define the coordiante for this dir
      Coord dirCoord = bearingCoord(currCoord,dir);

      if(checkBounds(dirCoord)){
        //if this dir is more optimal than continuing straight
        if(maze[dirCoord.getY()][dirCoord.getX()].distance < leastNextVal){
          //update teh value of leastNextVal
          leastNextVal = maze[dirCoord.getY()][dirCoord.getX()].distance;
          //update the value of leastnext to this dir
          leastNext = dirCoord;
          leastDir = dir;
        }
      }
    }
  }
  return leastDir;
}

//Take a coordinate and test if it is within the allowable bounds
boolean checkBounds(Coord c){
  if((c.getX() >= X) || (c.getY() >= Y) || (c.getX() < 0) || (c.getY() < 0))
    return false;
  else
    return true;
}

/*
INPUT: c
OUTPUT: An integer that is the least neighbor
*/
uint8_t checkNeighs(Coord c){
  uint8_t minVal =  255;

  for(int i=0; i<4; i++){
    uint8_t dir = headings[i];
    //if this dir is accessible
    /*if(c.getX()==4 && c.getY()==3){
        pf("DEBUG checkNeighs (4,3) walls %d, dir%d\n",maze[c.getY()][c.getX()].walls,dir);
        printMaze();
    }*/
    if((maze[c.getY()][c.getX()].walls & dir) != 0){
      //Get the coordinate of the accessible neighbor
      Coord neighCoord = bearingCoord(c, dir);
      //Check the value of the accessible neighbor
      if (checkBounds(neighCoord)){
        //if the neighbore is less than the current recording minimum value, update the minimum value
        //If minVal is null, set it right away, otherwise test
        if(maze[neighCoord.getY()][neighCoord.getX()].distance < minVal){
            minVal = maze[neighCoord.getY()][neighCoord.getX()].distance;
           // if(c.getX()==4 && c.getY()==3)pf("DEBUG checkNeighs (4,3)=%d (dir=%d, {%d,%d})\n",minVal,dir,neighCoord.getX(),neighCoord.getY());
        }
      }
    }
  }

  return minVal;
}

//Given a coordinate, test and return if the coordinate is bounded on three sides
boolean isDead(Coord c){
  boolean deadEnd = false;
  if(checkBounds(c)){
    uint8_t bounds = maze[c.getY()][c.getX()].walls;
    //bounds is the integer from the exploratory maze that represents the known walls of the coordinate
    if((bounds == 1)||(bounds == 2)||(bounds == 4) || (bounds == 8)){deadEnd=true;}
  }
  return deadEnd;
}

boolean isEnd(Coord c, Coord DesiredArray[],int lenArr){
  for(uint8_t i=0; i<lenArr;i++){

    Coord Desired = DesiredArray[i];
    //pf("DEBUG isEND: intento %d (%d,%d)==(%d,%d)\n",i,c.x,c.y,Desired.x,Desired.y);
    if(checkBounds(c)){
      if((c.getX() == Desired.getX())&&(c.getY()==Desired.getY())){
        return true;
      }
    }
  }
  return false;
}

/*
This function makes calls to the dispatcher to get the following info
  -orientation
  -surrounding walls
Using orientation and walls, this information is mapped to a map integer in the global coordinate frame
*/


uint8_t lastWall=4;
uint8_t readCurrent(uint8_t headingRobot, bool pR, bool pF, bool pL){
  uint8_t ret=0;
  switch(headingRobot){
    case NORTH:
        if(!pF)ret+=NORTH;
        if(!pR)ret+=EAST;
        if(!pL)ret+=WEST;
        return ret+SOUTH; //devuelvo las paredes detectadas mas la ausencia de pared por donde he venido
    case EAST:
        if(!pF)ret+=EAST;
        if(!pR)ret+=SOUTH;
        if(!pL)ret+=NORTH;
        return ret+WEST; //devuelvo las paredes detectadas mas la ausencia de pared por donde he venido
    case SOUTH:
        if(!pF)ret+=SOUTH;
        if(!pR)ret+=WEST;
        if(!pL)ret+=EAST;
        return ret+NORTH; //devuelvo las paredes detectadas mas la ausencia de pared por donde he venido
    case WEST:
        if(!pF)ret+=WEST;
        if(!pR)ret+=NORTH;
        if(!pL)ret+=SOUTH;

        return ret+EAST; //devuelvo las paredes detectadas mas la ausencia de pared por donde he venido
    default:
        return -1;
  }
}




/*
INPUT: Coordindate to update, and a direction representing the wall to add
OUTPUT: Update to coordinate adding the wall provided as an argument
*/
void coordUpdate(Coord coordinate, uint8_t wallDir){
  if(checkBounds(coordinate)){
    if((maze[coordinate.getY()][coordinate.getX()].walls & wallDir) != 0){
      maze[coordinate.getY()][coordinate.getX()].walls = maze[coordinate.getY()][coordinate.getX()].walls-wallDir;
    }
  }
}

/*
INPUT: Current Robot coordinate
OUTPUT: Update maze for learned walls
*/
void floodFillUpdate(Coord currCoord, Coord desired[], int lenDesired){
  StackList<Coord> entries;

  maze[currCoord.getY()][currCoord.getX()].walls=lastWall;

  entries.push(currCoord);

  for(uint8_t i=0; i<4; i++){
    uint8_t dir = headings[i];
    //If there's a wall in this dir
    if((maze[currCoord.getY()][currCoord.getX()].walls & dir) == 0){
      Coord workingCoord = Coord(currCoord.getX(),currCoord.getY());
      switch(dir){
        case 1:
          workingCoord.setY(workingCoord.getY()-1);
          coordUpdate(workingCoord,2);
          break;
        case 2:
          workingCoord.setY(workingCoord.getY()+1);
          coordUpdate(workingCoord,1);
          break;
        case 4:
          workingCoord.setX(workingCoord.getX()+1);
          coordUpdate(workingCoord, 8);
          break;
       case 8:
         workingCoord.setX(workingCoord.getX()-1);
         coordUpdate(workingCoord,4);
         break;
      }


      if(checkBounds(workingCoord)&&(!isEnd(workingCoord, desired,lenDesired))){
        entries.push(workingCoord);
      }
    }
  }


  //While the entries stack isn't empty
  while(!entries.isEmpty()){
    //pf("pila size: %d\n",entries.count());
    /*digitalWrite(RED_LED_PIN, HIGH);
    for(int i=0; i<entries.count(); i++) {
      digitalWrite(GREEN_LED_PIN, HIGH);
      delay(200);
      digitalWrite(GREEN_LED_PIN, LOW);
      delay(200);
    }
    delay(1000);
    digitalWrite(RED_LED_PIN, LOW);
    */
    //Pop an entry from the stack
    Coord workingEntry = entries.pop();
    uint8_t neighCheck = checkNeighs(workingEntry);
    //If the least neighbor of the working entry is not one less than the value of the working entry
    if(neighCheck+1!=maze[workingEntry.getY()][workingEntry.getX()].distance && !isEnd(workingEntry,desired,lenDesired)){
      maze[workingEntry.getY()][workingEntry.getX()].distance=neighCheck+1;
      for(uint8_t i=0;i<4;i++){
        uint8_t dir = headings[i];
        if((maze[workingEntry.getY()][workingEntry.getX()].walls & dir) != 0){
          Coord nextCoord = bearingCoord(workingEntry,dir);
          if(checkBounds(nextCoord)){
            if(!isEnd(nextCoord, desired,lenDesired)){
              entries.push(nextCoord);
            }
          }
        }
      }
    }
  }
}
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
void loop(){


  Coord desired[] = {Coord(5,5),Coord(5,6),Coord(5,7),Coord(6,5),Coord(6,6),Coord(6,7),Coord(7,5),Coord(7,6),Coord(7,7)};

  floodFill(desired,9, Coord(0,0),true);
  digitalWrite(GREEN_LED_PIN,HIGH);
  //while(1);
 //Serial.println("**FIN FLOOD_FILL 1");
  Order path[70];
  long lenPath=createSpeedQueue(Coord(0,0),desired,9,path,70);
  delay(3000);
  digitalWrite(GREEN_LED_PIN,LOW);//Serial.println("***VOLVIENDO AL ORIGEN****");
  Coord returnCoord3[] = {Coord(0,0)};
  resetToCoord(returnCoord3[0]);
  floodFill(returnCoord3,1, Coord(posXrobot,posYrobot),true);
  //Serial.println("*****FIN FLOOD_FILL Retorno*******");





  reflood(Coord(0,0),desired,9,path,lenPath);//Serial.println("*****FIN FLOOD_FILL Reflood****");

  //Serial.println("****END PROGRAM*******");

  while(1){
    digitalWrite(GREEN_LED_PIN,HIGH);
    while(!button_is_pressed());
    digitalWrite(GREEN_LED_PIN,LOW);
    delay(1000);
    run_path(path,200);
    delay(2000);
  }



}

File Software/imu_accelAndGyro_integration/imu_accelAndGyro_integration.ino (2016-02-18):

// Based on:
// MPU-6050 Short Example Sketch by Arduino User JohnChi

#include<Wire.h>

const int MPU=0x68;  // I2C address of the MPU-6050

#define MPU6050_PWR_MGMT_1    0x6B
#define MPU6050_ACCEL_CONFIG  0x1C
#define MPU6050_GYRO_CONFIG   0x1B
#define MPU6050_SMPLRT_DIV    0x19
#define MPU6050_CONFIG        0x1A

void init_IMU() {
  for(int i=0; i<3; i++) { // Reset the IMU a few times
    IMUwriteReg(MPU6050_PWR_MGMT_1, bit(7) );  // DEVICE_RESET to 1 (D7=1)
    delay(100);
  }

  IMUwriteReg(MPU6050_PWR_MGMT_1, bit(0) | bit(1) ); // set clock source to Z Gyro (D0=D1=1, D2=0) and set SLEEP to zero (D6=0, wakes up the MPU-6050)

  IMUwriteReg(MPU6050_ACCEL_CONFIG, bit(3) | bit(4) ); // set sensitivity to +-16G (D3=1, D4=1) and disable high pass filter (D0,D1,D2=0)

  IMUwriteReg(MPU6050_GYRO_CONFIG, bit(3) | bit(4) ); // set sensitivity to +-2000deg/s (D3=1, D4=1)

  IMUwriteReg(MPU6050_SMPLRT_DIV, 0 ); // set sampling rate to 1khz (1khz / (1 + 0) = 1000 Hz)

  IMUwriteReg(MPU6050_CONFIG, bit(0) | bit(5) ); // disable digital low pass filter (D0=D1=D2=0) and EXT_SYNC to GYRO_ZOUT (D3=D4=0, D5=1)
}


#define LED_RED_PIN     13
#define LED_GREEN_PIN   9

#define BUZZER_PIN      8

#define M1A_PIN         11
#define M2A_PIN         10
#define M4A_PIN         5
#define M3A_PIN         6

#define BUTTON_PIN      7

#define LINE_R_PIN      2
#define LINE_M_PIN      3
#define LINE_L_PIN      4

#define DIST_3_PIN      A3
#define DIST_2_PIN      A2
#define DIST_1_PIN      A1

#define BATTERY_V_PIN   A0

void init_motor_pins() {
  pinMode(M1A_PIN,OUTPUT);
  pinMode(M2A_PIN,OUTPUT);
  pinMode(M3A_PIN,OUTPUT);
  pinMode(M4A_PIN,OUTPUT);
}

void LmotorSpeed(int16_t vel) {
  if(vel > 0) {
    analogWrite(M1A_PIN, 0);
    analogWrite(M2A_PIN, vel);
  } else if(vel < 0) {
    analogWrite(M1A_PIN, -vel);
    analogWrite(M2A_PIN, 0);
  } else {
    analogWrite(M1A_PIN, 0);
    analogWrite(M2A_PIN, 0);
  }
}

void RmotorSpeed(int16_t vel) {
  if(vel > 0) {
    analogWrite(M3A_PIN, 0);
    analogWrite(M4A_PIN, vel);
  } else if(vel < 0) {
    analogWrite(M3A_PIN, -vel);
    analogWrite(M4A_PIN, 0);
  } else {
    analogWrite(M3A_PIN, 0);
    analogWrite(M4A_PIN, 0);
  }
}



// --- BUTTON ---
void init_button_pin() {
  pinMode(BUTTON_PIN,INPUT);
  digitalWrite(BUTTON_PIN, HIGH); // Enable internal pull-up resistor
}
// Returns 1 if the button is being pressed, 0 if it is not
int button_is_pressed() {
  return !digitalRead(BUTTON_PIN);
}




int16_t AcY, GyZ;
int16_t AcYoffset, GyZoffset;
float AcY_integral, GyZ_integral;

unsigned long prev_ts;

void IMUwriteReg(byte reg, byte val) {
  Wire.begin();
  Wire.beginTransmission(MPU);
  Wire.write(reg);
  Wire.write(val);
  Wire.endTransmission(true);
}

void setup() {
  delay(400);
  
  init_motor_pins();
  init_button_pin();
  pinMode(LED_RED_PIN, OUTPUT);
  pinMode(LED_GREEN_PIN, OUTPUT);
  
  digitalWrite(LED_RED_PIN, HIGH);

  init_IMU();
  
  Serial.begin(115200);
  delay(1000);
  
  // Measure IMU sensor offsets (robot must remain still)
  AcYoffset = 0;
  GyZoffset = 0;
  for(int i=0; i<10; i++) {
    readIMU(&AcY, &GyZ);
    AcYoffset += AcY;
    GyZoffset += GyZ;
  }
  AcYoffset /= 10;
  GyZoffset /= 10;
  Serial.println("Offset:");
  Serial.println(AcYoffset);
  Serial.println(GyZoffset);
  
  
  digitalWrite(LED_RED_PIN, LOW);
  digitalWrite(LED_GREEN_PIN, HIGH);
  
  //while(!button_is_pressed());
  
  prev_ts = millis();
  
  AcY_integral = 0;
  GyZ_integral = 0;
}

void readIMU(int16_t *AcY, int16_t *GyZ) {
  Wire.beginTransmission(MPU);
  Wire.write(0x3D);  // starting with register 0x3D (ACCEL_YOUT_H)
  Wire.endTransmission(false);
  Wire.requestFrom(MPU,12,true);  // request a total of 12 registers
  *AcY = Wire.read()<<8|Wire.read();  // 0x3D (ACCEL_YOUT_H) & 0x3E (ACCEL_YOUT_L)
  for(int i=0; i<8; i++) Wire.read(); // Discard 0x3F-0x46
  *GyZ = Wire.read()<<8 | Wire.read();  // 0x47 (GYRO_ZOUT_H) & 0x48 (GYRO_ZOUT_L)
}


int iter = 0;
float linear_motion_big = 0;
unsigned long contTs = 0;

void loop() {
  readIMU(&AcY, &GyZ);
  unsigned long ts = micros();
  float dt = ((float)(ts-prev_ts))/1000000.;
  if(dt > 0) { // Ensures the integration only over sensible sampling intervals
    linear_motion_big += AcY_integral*dt;
    AcY_integral += (AcY-AcYoffset)*dt;
    
    GyZ_integral += (GyZ-GyZoffset)*dt;
  }
  
  float linear_motion = 0;//linear_motion_big*16./32768.; // +-16G sensitivity; +-2^15 full scale
  float rotation = GyZ_integral*2000./32768.; // +-2000 deg/s sensitivity; +-2^15 full scale
  
  int rot_error = max(min(round(255.*rotation/90.),255),-255);
  int dist_error = max(min(round(255.*(40-1000*linear_motion)/300.),255),-255);
  
  //Serial.println(AcY);

  if( (contTs+5000) < millis() ){
    contTs = millis();
    digitalWrite(LED_GREEN_PIN, HIGH);
    GyZ_integral += (90./2000.)*32768.;
  }
  
  if((iter % 10) == 0) {
    if(1000*linear_motion > 20) {
      LmotorSpeed(0);
      RmotorSpeed(0);
      digitalWrite(LED_RED_PIN, HIGH);
      while(1);
    } else {
      LmotorSpeed(dist_error+rot_error);
      RmotorSpeed(dist_error-rot_error);
    }
    /*Serial.print(rotation);
    Serial.print("\t");
    Serial.println(linear_motion);*/
  }
  prev_ts = ts;
  iter++;

  /*if(button_is_pressed()) {
    linear_motion = 0;
    AcY_integral = 0;
    GyZ_integral = 0;
    delay(1000);
  }*/
  //delay(10);
}

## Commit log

2015-10-28 Generated schematic & layout
2015-10-28 Linked authors
    [CRMaze.scad]
2015-10-28 Linked board picture
2015-10-28 Generated wheel stl
    [CRMaze.scad, wheel.stl]
2015-10-29 Fixed track
    [laberinto.kicad_pcb]
2015-10-30 Added IMU code
2015-10-30 Added super optimized code by Davide Gironi
    [atmega8_mpu6050_sample.sch]
2015-10-30 Added motor+buzzer test
2015-10-30 Updated wheels & code
    [CRMaze.scad, wheel.stl]
2015-10-30 antes de liarla parda
2015-10-30 Motor functions
2015-10-31 Added compass & IMU tests. Evaluated memory requirements. Simple angle integration achieved
2015-10-31 The gyro is workinggit add -Agit add -A! :-)
2015-10-31 Implemented yaw proportional controller
2015-11-03 Updated filter settings
2015-11-03 Updated wheel to minimize the effect of distortions introduced by the 3D printer
    [CRMaze.scad, wheel.stl]
2015-11-04 Added PID code
2015-11-04 Added sensor support
    [CRMaze.scad, laberinto-B_Cu.dxf, laberinto-Edge_Cuts.dxf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]
2015-11-04 Prueba de los sensores IR
2015-11-04 sensor_support v2
    [CRMaze.scad, sensor_support2.stl]
2015-11-04 Incorporated IR sensor measurements so the robot goes straight
2015-11-06 Calibrado con el tablero oficial
2016-02-07 Añadido código que no se había subido a github
2016-02-07 Añadidas algunas fotos del proceso de diseño y construccion del robot
2016-02-07 Añadido backup del vídeo de fresado del PCB
2016-02-18 cuadrado con integracion de gyro
2016-09-08 Añadido laberinto
    [paredes_laberinto.scad, paredes_laberinto.stl, pieza_suelta.stl]
2016-09-11 columnas laberinto
    [columnas_laberinto.stl, paredes_laberinto.scad]
2016-09-26 Nuevo diseño de laberinto con columnas y paredes por separado y montaje por inserciones
    [laberinto_v2.scad]
2016-10-20 Añadida foto
    [CRMaze.scad]
2017-10-31 Añadidas piezas laberinto 2017
    [pilarLaberinto2017.stl, pilaresLaberinto2017.scad, pilaresLaberinto2017.stl]
